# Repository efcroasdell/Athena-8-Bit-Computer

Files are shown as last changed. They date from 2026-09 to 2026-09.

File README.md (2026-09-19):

# Athena 8-Bit Computer

Athena is a practical 8-bit computer build and associated learning, measurement, verification, and documentation project.

This repository is the **authoritative engineering record** for Athena. Chat history may support the work, but established designs, measurements, decisions, experiments, faults, and evidence should be recorded here.

Athena is published as an engineering and learning record. Pull requests and issues are not currently accepted, but discussion and technical questions are welcome via GitHub Discussions.

## Scope

The repository is intended to hold:

- KiCad schematics and PCB/design files
- breadboard build records and wiring information
- photographs
- oscilloscope captures
- logic-analyser captures
- measurements and test results
- design decisions and architectural notes
- experiments and fault reports
- datasheets and reference material
- firmware, programs, scripts, and utilities
- superseded designs and failed experiments retained for historical and learning value

## Project boundary

**Athena is separate from Phoenix.**

Athena is the practical 8-bit computer build and its associated learning/documentation record. Phoenix is the separate modular computer architecture project centred on FPGA/Verilog and broader modular multi-processor exploration. Phoenix material must not be placed in this repository.

## Engineering approach

The project prioritises understanding, observability, and verification. Measurements, scope traces, logic-analyser captures, photographs, and controlled experiments are treated as engineering evidence rather than incidental artefacts.

Provisional ideas, confirmed decisions, superseded work, and failed experiments should remain distinguishable in the record rather than being silently overwritten.

Athena should favour understandable and verifiable solutions, but it need not always favour the most conventional solution. Unusual, historically interesting or unexpected period-appropriate devices and architectures may be explored where they add educational value, observability or understanding. Novelty is not itself a requirement and must not displace electrical correctness or clear verification.

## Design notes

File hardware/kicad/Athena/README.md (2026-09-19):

# Athena clock schematic

Open `Athena.kicad_pro` and enter the **Clock** sheet. `exports/Athena-clock.pdf` is the complete clock drawing on one A3 page.

The schematic now contains both halves of U1 (RS 305-838 / NE556), all five units of U2 (TI SN7400), U3 (TI SN74LS157N), U4 (TI CD40106BE), both timing networks, the RC/Schmitt STEP-debounce network, RUN/MANUAL controls, HLT gating, and only the two required LEDs. Signal paths are drawn with continuous wires. A dot at a crossing means connected; crossings without dots are not connected. Matching +5 V and ground symbols denote the common supply rails. PWR_FLAG is an electrical-check annotation, not a physical part.

## Defined connections

- U4 pin 1 is the debounce RC node: R3 = 47 kΩ to +5 V, C6 = 100 nF to GND, and R9 = 1 kΩ in series with SW1 to GND.
- U4 pin 2 feeds U4 pin 3; U4 pin 4 feeds U1 pin 8. This gives two Schmitt inversions and preserves the active-LOW STEP trigger polarity.
- U4 pin 14 is connected to +5 V and pin 7 to GND. Unused U4 inputs are tied to GND and unused outputs are marked unconnected.

- U1 pin 5 feeds U3 pin 3 (astable); U1 pin 9 feeds U3 pin 2 (manual).
- U2 pin 6 feeds U3 pin 1: LOW selects MANUAL, HIGH selects ASTABLE.
- U3 pin 4 feeds U2 pin 9. U2 pin 8 feeds U2 pins 12 and 13.
- U2 pin 11 is the external CPU_CLK output. No connector type or terminal numbering is assumed.
- U2 pin 10 is CLOCK_ENABLE. Closing SW3 pulls it LOW, lights D1 and holds CPU_CLK LOW.
- U3 pin 15 and unused data inputs are grounded; unused outputs are marked unconnected.
- U1A/B are one physical DIP-14 IC. U2A-E are one physical DIP-14 IC. U3 is DIP-16. U4A-G are one physical DIP-14 CD40106BE.

## Details still requiring confirmation

| Reference/detail | Meaning |
|---|---|
| R4, R5 | Fitted RUN/MANUAL pull-up resistances unknown: TBC |
| R7, R8 | Fitted HLT and astable LED series resistances unknown: TBC |
| D2 | Signal is confirmed as U1 pin 5; complete LED wiring/polarity to GND shown provisionally |
| RV1 unused end | Shown open; confirm whether strapped to the wiper |
| SW2 | Functional contacts shown; physical switch terminal numbering/type needs confirmation |
| C3, C4, C5 | Local supply bypass provisions for U1, U2, U3 respectively; fitted presence and values TBC |
| U4 local decoupling | Existing 100 nF rail decoupling is present close to the device on the breadboard; exact schematic reference/fitted placement remains to be reconciled if a dedicated capacitor reference is wanted |
| U3 unused data inputs | Grounded as required by the wiring record; verify actual breadboard connections |

U1 control pins 3 and 11 are externally unconnected in this drawing. Optional control bypass capacitors are not shown as fitted. The unknown details remain explicit rather than being guessed. Resolve them before using this as a definitive as-built record or final build specification. Footprints and PCB layout are outside this schematic update.

## Verification

The core connections follow `../../breadboard/clock/wiring.md`, `../../../docs/design-decisions/clock-architecture.md` and the user's confirmed values. All 44 IC pins were checked in the exported netlist, including power/reset, both timing networks, latch feedback, selector routing, HLT and LED connections. Actual pin membership was checked against expected sets to detect unintended joins.

KiCad **10.0.3** loaded the schematic in the existing Athena hierarchy. ERC reports **0 errors and 1 warning**: CPU_CLK is connected only to U2 pin 11 because the receiving CPU circuit is outside this module. This warning remains visible; no check was disabled to hide it. See `exports/Clock-erc.txt`.

The selector/output path was rechecked on the bench on 19 September 2026 and behaved correctly. The Clock schematic and Clock-logic sheet have now been revised to include the CD40106B STEP-debounce stage. The previously exported PDF/ERC files pre-date this revision and must be regenerated in KiCad 10.0.3 before they are treated as current verification artefacts.

The original top-level schematic and existing project settings were retained. Journal content was not edited as part of this work.

## Logic diagram

The **Clock logic** hierarchical sheet (`Clock-logic.kicad_sch`) now also identifies the CD40106B STEP-conditioning stage before the manual 556 path, alongside source selection, mode memory, both HLT NAND gates and the Boolean relationships. `exports/Clock-logic.pdf` is its A4 preview. This sheet contains documentation graphics only and is excluded from the BOM, board and simulation. Its U1/U2/U3 annotations refer to the existing physical ICs on the Clock circuit sheet; it adds no duplicate parts or electrical nets.

## 19 September 2026 schematic update

The Clock sheet has been revised to match the current physical STEP path:

- CD40106B pin 1 → 47 kΩ → +5 V;
- CD40106B pin 1 → 100 nF → GND;
- CD40106B pin 1 → 1 kΩ → STEP switch → GND;
- CD40106B pin 2 → pin 3;
- CD40106B pin 4 → U1 pin 8;
- CD40106B pin 14 → +5 V;
- CD40106B pin 7 → GND;
- unused CD40106B inputs are tied to GND; unused outputs are marked unconnected.

The former direct 10 kΩ pull-up / STEP-switch connection at U1 pin 8 is superseded. R3 is now 47 kΩ, C6 is 100 nF and R9 is 1 kΩ.

Bench verification on 19 September 2026 established that the conditioning stage produces a clean trigger at U1 pin 8 and one clean CPU clock pulse per deliberate STEP action. In RUN, STEP produced no observable disturbance at U3 pin 4, U2 pin 9 or U2 pin 11.

**Export status:** the editable KiCad schematic files are current, but the committed PDF preview and ERC report still represent the earlier revision until regenerated in KiCad 10.0.3.

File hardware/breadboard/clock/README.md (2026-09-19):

# Athena Clock Module

## Purpose

The Athena clock module provides the timing and manual stepping functions required by the 8-bit computer while preserving the user-facing behaviour of the original Ben Eater clock module:

- variable-speed free-running clock
- manual single-step clock
- RUN/MANUAL mode selection
- HLT-controlled clock gating
- final CPU clock output
- observable intermediate signals for verification and learning

The current implementation is intentionally compact but remains built from discrete TTL-era functions so that each stage can be observed and understood directly.

## Current architecture

The current clock uses four main ICs:

| Device | Function in Athena |
|---|---|
| RS 305-838 dual 556 timer | Timer 1: astable free-running clock. Timer 2: monostable manual STEP pulse. |
| TI CD40106BE hex Schmitt-trigger inverter | RC + hysteretic conditioning of the mechanical STEP input. Two inverter stages preserve active-LOW trigger polarity. |
| TI SN7400 standard TTL quad NAND | RUN/MANUAL latch and HLT clock gating. |
| TI SN74LS157N quad 2-to-1 multiplexer | Selects manual or astable clock source. |

Functional signal path:

1. 556 Timer 1 generates the variable-speed astable clock.
2. The STEP push-button is filtered by a 47 kΩ / 100 nF RC network and two CD40106B Schmitt inverters.
3. 556 Timer 2 generates one monostable pulse for each clean active-LOW STEP trigger.
4. The SN7400 cross-coupled NAND latch stores the RUN/MANUAL state.
5. The SN74LS157 selects either the manual pulse or the astable clock according to the stored mode.
6. The remaining SN7400 gates apply HLT control to the selected clock.
7. SN7400 pin 11 is the final internal CPU clock output.

## 556 pinout used in this build

The RS 305-838 dual 556 pinout has been verified as:

| Pin | Signal |
|---:|---|
| 1 | DISCHARGE1 |
| 2 | THRESHOLD1 |
| 3 | CONTROL1 |
| 4 | RESET1 |
| 5 | OUTPUT1 |
| 6 | TRIGGER1 |
| 7 | GND |
| 8 | TRIGGER2 |
| 9 | OUTPUT2 |
| 10 | RESET2 |
| 11 | CONTROL2 |
| 12 | THRESHOLD2 |
| 13 | DISCHARGE2 |
| 14 | VCC |

Timer 1 is configured as an astable oscillator. Timer 2 is configured as a monostable single-step generator.

## Timer 1: astable clock

Current functional connections:

- pin 14 → +5 V
- pin 7 → GND
- pin 4 → +5 V
- pins 2 and 6 joined as the timing-capacitor node
- fixed timing resistor from +5 V to pin 1
- 1 MΩ speed-control potentiometer between pin 1 and the joined pins 2/6
- 1 µF timing capacitor from pins 2/6 to GND
- pin 5 = astable clock output

The timing node repeatedly charges and discharges between approximately one-third and two-thirds of VCC. The internal threshold and trigger comparators change the state of the timer latch at those points, while the discharge transistor on pin 1 controls the capacitor discharge interval.

## Timer 2: manual STEP monostable

Current functional connections:

- pin 8 = active-LOW STEP trigger driven by CD40106B pin 4
- CD40106B pin 1 is the debounce node: 47 kΩ to +5 V, 100 nF to GND, and 1 kΩ in series with the normally-open STEP switch to GND
- CD40106B pin 2 → pin 3; pin 4 → 556 pin 8
- pin 9 = monostable output
- pin 10 → +5 V
- pin 11 normally unconnected; optional small control-voltage bypass may be fitted
- pins 12 and 13 joined as the monostable timing node
- 1 MΩ timing resistor from +5 V to pins 12/13
- 1 µF timing capacitor from pins 12/13 to GND

At rest, the CD40106B holds pin 8 HIGH and pin 9 is LOW. Pressing STEP discharges the RC node; the Schmitt thresholds convert the slow, potentially bouncing mechanical transition into one clean LOW-going trigger at pin 8. Pulling pin 8 below the internal trigger threshold sets the internal latch, drives pin 9 HIGH, turns the discharge transistor off, and allows the timing capacitor to charge. When the timing node reaches the upper threshold, the threshold comparator resets the latch, pin 9 returns LOW, and the discharge transistor restores the timing node to its idle state.

## SN7400 functions

The SN7400 uses all four NAND gates.

| Gate | Pins | Function |
|---|---|---|
| Gate 1 | 1,2 → 3 | First half of cross-coupled RUN/MANUAL latch |
| Gate 2 | 4,5 → 6 | Second half of cross-coupled RUN/MANUAL latch; pin 6 is Q |
| Gate 3 | 9,10 → 8 | First stage of HLT clock gating |
| Gate 4 | 12,13 → 11 | Inverts gate-3 result to restore final clock polarity |

Pin 6, Q, drives the SELECT input of the SN74LS157.

HLT control is applied at SN7400 pin 10. The current behaviour has been verified:

- pin 10 HIGH → selected clock passes through to pin 11 with the intended polarity
- pin 10 LOW → final clock pin 11 is held LOW

An HLT indicator LED is connected so that it illuminates when the HLT control node is LOW.

## SN74LS157 clock-source selector

Channel 1 is used for clock selection:

| Pin | Function in Athena |
|---:|---|
| 1 | SELECT ← SN7400 pin 6 (Q) |
| 2 | 1A ← 556 pin 9 manual STEP output |
| 3 | 1B ← 556 pin 5 astable output |
| 4 | 1Y → SN7400 pin 9 selected-clock input |
| 8 | GND |
| 15 | active-LOW strobe tied to GND |
| 16 | +5 V |

The selector function is:

Y = A·Q̄ + B·Q

so one clock source is selected according to the stored RUN/MANUAL state.

Unused LS157 data inputs are intended to be tied to a defined logic level rather than left floating. Unused outputs may remain open.

## Current verification status

Confirmed so far:

- 556 Timer 1 astable operation and timing-node behaviour
- 556 Timer 2 pin 8 active-LOW trigger behaviour
- 556 Timer 2 pin 9 idle LOW state and triggered HIGH pulse
- 556 Timer 2 pin 10 steady HIGH reset input
- 556 Timer 2 pin 11 steady control/reference level
- 556 Timer 2 pin 12 idle timing-node level and triggered exponential charge followed by rapid discharge
- CD40106B STEP debounce operation
- one STEP press producing one clean CPU clock pulse in the post-debounce DSLogic capture
- SN7400 RUN/MANUAL latch operation
- SN7400 HLT gating behaviour
- SN74LS157 enable state and SELECT input operation
- RUN-mode rejection of the manual STEP path verified at SN74LS157 pin 4, SN7400 pin 9 and SN7400 pin 11
- final CPU clock independently measured at approximately 270.407 kHz during the 19 September 2026 RUN-mode regression check

Systematic pin-by-pin 556 verification has reached pin 12, with pins 8, 9 and 12 checked in both idle and triggered states. Pins 13 and 14 remain to be documented. The manual STEP debounce and selector propagation path are now independently verified.

## Evidence and measurement record

Detailed oscilloscope measurements, expected behaviour, observed values, and explanations of the internal 556 mechanisms belong in the corresponding measurement journal under `docs/measurements/`.

Photographs and oscilloscope captures should be stored under `evidence/` and referenced from the journal by filename so that the written conclusion remains tied to the original evidence.

## Status

**Current architectural decision:** 556 + SN7400 + SN74LS157 implementation.

**Current verification state:** the clock architecture, RUN/MANUAL selection, HLT gating and debounced manual STEP path are functionally verified; remaining work is completion of the formal pin-by-pin 556 documentation and evidence indexing.

**Project boundary:** this clock module belongs to Athena. Phoenix FPGA/multi-processor architecture material is not part of this repository.

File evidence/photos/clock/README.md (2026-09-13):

# Clock Module Photographic Evidence

Store photographs of the Athena clock-module breadboard and component wiring in this directory.

Photographs are engineering evidence. Each image should be treated as a record of the circuit at that moment rather than as an illustration of what the circuit was expected to be.

Use filenames that identify the subject and date where practical, for example:

- `clock-overview-2026-09-13.jpg`
- `556-step-switch-wiring-2026-09-13.jpg`
- `556-timer2-timing-network-2026-09-13.jpg`
- `sn7400-run-manual-latch-2026-09-13.jpg`
- `sn74ls157-clock-selector-2026-09-13.jpg`

Where a photograph is used to support a wiring or fault conclusion, reference its filename from the corresponding Markdown record.

Project rule: **every photograph is fresh evidence**. Trace only connections that are actually visible. Do not infer a missing connection from the expected schematic or from an earlier photograph.

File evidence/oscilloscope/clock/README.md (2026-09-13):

# Clock Module Oscilloscope Evidence

Store original oscilloscope captures for the Athena clock module in this directory.

Use filenames that identify the device, pin or node, state and date where practical. Examples:

- `556-pin01-discharge1-2026-09-13.jpg`
- `556-pin08-trigger2-idle-2026-09-13.jpg`
- `556-pin08-trigger2-pressed-2026-09-13.jpg`
- `556-pin09-output2-idle-2026-09-13.jpg`
- `556-pin09-output2-triggered-2026-09-13.jpg`

The written measurement record belongs in `docs/measurements/clock-556-verification.md` and should link to the original evidence files stored here.

Do not alter an original capture merely to make it agree with an expected result. If annotated or cropped versions are useful, retain the original and store the derivative with a clearly different filename.

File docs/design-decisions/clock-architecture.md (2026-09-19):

# Clock Architecture Decision Record

Status: **current architectural decision**

## Decision

Athena's clock module will retain the functional behaviour of the Ben Eater 8-bit computer clock while using a more compact implementation based on:

- one RS 305-838 dual 556 timer
- one TI CD40106BE hex Schmitt-trigger inverter
- one TI SN7400 standard TTL quad NAND gate
- one TI SN74LS157N quad 2-to-1 multiplexer

This is an Athena decision. It is not a Phoenix architectural rule.

## Required external behaviour

The clock module must provide:

- variable-speed free-running clock
- manual single-step operation with hardware debounce and hysteretic edge conditioning
- persistent RUN/MANUAL mode selection
- clean clock-source selection
- HLT-controlled clock gating
- final CPU clock output
- observable intermediate nodes for measurement and diagnosis

## Functional allocation

### 556 Timer 1 — astable source

Timer 1 produces the free-running variable-speed clock. The timing capacitor repeatedly traverses the internal trigger and threshold reference levels, approximately one-third and two-thirds of VCC. The internal latch and discharge transistor create the repeating charge/discharge cycle.

### CD40106B — STEP input conditioning

The mechanical STEP input is conditioned before it reaches the 556.

The current network is:

- 47 kΩ from the CD40106B pin-1 debounce node to +5 V;
- 100 nF from the pin-1 node to GND;
- 1 kΩ from the pin-1 node through the normally-open STEP switch to GND;
- CD40106B pin 2 connected to pin 3;
- CD40106B pin 4 driving 556 pin 8.

Two Schmitt inverter stages are used so that hysteresis cleans the mechanical transition while the second inversion restores the required active-LOW trigger polarity.

### 556 Timer 2 — manual monostable

Timer 2 produces one manual clock pulse for each clean active-LOW STEP trigger from the CD40106B. Its timing interval is determined by the external 1 MΩ / 1 µF timing network.

### SN7400 gates 1 and 2 — RUN/MANUAL memory

The first two NAND gates are cross-coupled to form an SR latch. The latch stores the selected operating mode rather than requiring the selector switch itself to carry the clock signal.

The chosen convention is:

- SN7400 pin 6 = Q
- SN7400 pin 3 = complementary output

Q drives the SELECT input of the SN74LS157.

### SN74LS157 — clock-source selection

One multiplexer channel selects between:

- A = manual pulse from 556 pin 9
- B = astable clock from 556 pin 5

with Q from the SN7400 latch controlling SELECT.

The intended selector relationship is:

`Y = A·Q̄ + B·Q`

The active-LOW strobe is tied LOW so the selector remains enabled.

### SN7400 gates 3 and 4 — HLT gating

The remaining two NAND gates provide the final HLT gating function. The two-gate arrangement restores the selected clock to the intended polarity at the final output.

Verified behaviour:

- HLT control HIGH → selected clock propagates to final clock output
- HLT control LOW → final clock output is held LOW

SN7400 pin 11 is the current final internal CPU clock output.

## Why this architecture was chosen

The design keeps the full educational value of the original clock while reducing package count and making the signal path explicit.

The implementation exposes several distinct concepts in one small subsystem:

- analogue RC timing
- internal comparator thresholds
- SR-latch state
- TTL NAND logic
- multiplexing
- active-LOW control
- clock gating
- propagation through multiple logic stages
- oscilloscope verification of analogue and digital behaviour

The 556 is particularly useful because it places the astable and monostable functions in one package while preserving the same internal timer mechanisms that can be observed and understood individually.

The CD40106B was not selected by following an existing Z80 clock plan. It was introduced after measurement and fault isolation showed that repeated clock events originated in mechanical STEP-input chatter. The design therefore arose from the observed failure mechanism: contact bounce required a slowly varying RC node to be converted into a single unambiguous logic transition, for which a Schmitt input is directly suited.

This is an important Athena design principle: the project should prefer understandable and verifiable solutions, but it need not always choose the most conventional solution. Unusual, historically interesting or unexpected period-appropriate devices and architectures may be explored where they increase educational value, observability or understanding. Novelty is not itself a requirement and must not obscure electrical correctness.

## Rejected or superseded approaches

### Multiple 555 timers

The original learning path used separate 555 timers. This remains historically important and is retained in the archive, but it is not the current Athena clock architecture.

Reason for supersession: the dual 556 implements the two required timer functions in one package without hiding the timing mechanism.

### Treating the RUN/MANUAL control as direct clock switching

Rejected. Mode state is retained in the NAND latch and then applied to the multiplexer. This makes the state explicit and independently observable.

### Alternative STEP-debounce approaches considered

The following alternatives were investigated before the CD40106B implementation was selected:

- CD4093BE Schmitt NAND logic;
- comparator-based hysteresis using LM393, HA17393 or AN1319 devices;
- a NAND SR-latch debounce circuit with an SPDT momentary switch;
- 74LS123 monostable conditioning;
- flip-flop-based approaches;
- altering the existing 556 trigger network.

These alternatives remain technically interesting. They were not rejected as invalid in general; they were not selected for this milestone because the CD40106B directly addresses the observed bounce mechanism with fewer additional parts and a clear test method.

### Moving the clock function into FPGA logic

Not part of the current Athena clock milestone. The purpose of this module is to understand and measure the physical timer, TTL, switching and gating behaviour directly.

## Observability requirement

The following points should remain practically observable during development:

- 556 astable timing node
- 556 astable output
- mechanical STEP switch
- CD40106B RC debounce node
- CD40106B conditioned STEP output
- 556 monostable trigger
- 556 monostable output
- RUN/MANUAL latch outputs
- LS157 SELECT
- LS157 selected clock output
- HLT control
- final CPU clock

Observability is a design objective, not an incidental debugging convenience.

## Verification requirement

The architecture is not considered fully verified merely because the final clock appears to work. Each stage must be checked against its expected behaviour and, where useful, against the internal mechanism that produces that behaviour.

The manual STEP debounce and complete selector/final-clock propagation path were rechecked end-to-end on 19 September 2026. One STEP press produced one clean CPU clock pulse in the post-debounce logic-analyser capture, and in RUN mode a STEP action produced no observable disturbance at SN74LS157 pin 4, SN7400 pin 9 or SN7400 pin 11. Formal pin-by-pin documentation of the remaining 556 pins continues separately.

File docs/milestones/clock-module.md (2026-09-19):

# Athena Milestone — Clock Module

Status: **in progress**

## Purpose

Produce and verify a complete clock subsystem for Athena that preserves the functional behaviour required by the Ben Eater 8-bit computer while making each timing, selection and gating stage observable and understandable.

## Current implementation

- RS 305-838 dual 556
  - Timer 1: variable-speed astable clock
  - Timer 2: manual monostable STEP pulse
- TI CD40106BE
  - RC + Schmitt-trigger conditioning of the mechanical STEP input
- TI SN7400
  - RUN/MANUAL state latch
  - HLT clock gating
- TI SN74LS157N
  - manual/astable clock-source selection

## Prerequisites

- stable +5 V supply
- common ground reference
- verified IC orientation and pinout
- oscilloscope available for analogue timing and digital waveform checks
- known-good STEP, RUN/MANUAL and HLT controls

## Model

The clock module consists of five observable functional stages:

1. generation of a free-running clock by the 556 astable timer;
2. RC filtering and Schmitt-trigger conditioning of the mechanical STEP input;
3. generation of one manual pulse by the 556 monostable timer;
4. persistent RUN/MANUAL state stored by the SN7400 latch and applied to the SN74LS157 selector;
5. HLT gating of the selected clock through the remaining SN7400 gates.

The final internal CPU clock is SN7400 pin 11.

## Expected behaviour

### Astable mode

The timing capacitor repeatedly charges and discharges between approximately one-third and two-thirds of VCC. 556 pin 5 produces a corresponding square-wave clock whose frequency varies with the speed potentiometer.

### Manual mode

The STEP switch acts on a 47 kΩ / 100 nF RC node at CD40106B pin 1. Schmitt hysteresis converts the mechanical transition into a clean logic event. A second inverter restores the original polarity so 556 pin 8 is HIGH at rest and receives one clean LOW-going trigger for each valid STEP action. Pin 9 then produces one HIGH monostable pulse before returning automatically to LOW.

### Selection

The SN7400 RUN/MANUAL latch retains the chosen mode. Its Q output drives SN74LS157 SELECT so that only the appropriate clock source reaches the selected-clock output.

### Halt

HLT inactive permits the selected clock to propagate to the final clock output. HLT active forces the final clock LOW.

## Observability

The following nodes must remain measurable during this milestone:

- Timer 1 discharge node
- Timer 1 timing capacitor / threshold / trigger node
- Timer 1 control reference
- Timer 1 output
- mechanical STEP switch
- CD40106B debounce RC node
- CD40106B conditioned output
- Timer 2 trigger
- Timer 2 output
- Timer 2 timing node
- RUN/MANUAL latch Q and complementary output
- LS157 SELECT
- LS157 selected-clock output
- HLT control
- final CPU clock

## Predicted results

- Timer 1 timing node: ramp between roughly one-third and two-thirds VCC
- Timer 1 output: clean TTL-compatible square wave
- Timer 2 trigger: HIGH at rest, LOW while STEP is pressed
- Timer 2 output: LOW at rest, one HIGH pulse per valid trigger
- RUN/MANUAL latch: stable complementary states until deliberately changed
- selected clock: only the chosen source appears at LS157 output
- HLT active: final clock remains LOW
- HLT inactive: final clock follows selected source with intended polarity

## Acceptance criteria

The clock milestone is complete when:

- all relevant 556 pins have been measured and documented;
- astable frequency changes predictably with the speed control;
- one STEP action produces one clean manual output pulse and one clean final CPU clock event;
- RUN/MANUAL state is stable and repeatable;
- source selection is verified at the LS157 input and output pins;
- HLT reliably suppresses the final clock;
- final clock waveform is measured directly;
- no input required to hold a defined state is left floating;
- the current breadboard wiring record matches the physical build;
- evidence files are linked from the measurement record.

## Fault tests

Controlled tests should include:

- force Timer 2 trigger LOW with a jumper and confirm the expected response;
- change RUN/MANUAL state and confirm LS157 SELECT changes accordingly;
- activate HLT while the astable source continues running and confirm only the final clock is suppressed;
- verify that removing a control action returns the node to its defined pull-up or stable state;
- where a waveform is suspicious, distinguish source behaviour from probe/ground artefacts before assigning a component fault.

## Required documentation

- `hardware/breadboard/clock/README.md`
- `hardware/breadboard/clock/wiring.md`
- `docs/design-decisions/clock-architecture.md`
- `docs/measurements/clock-556-verification.md`
- `docs/faults/clock-fault-history.md`
- oscilloscope evidence under `evidence/oscilloscope/clock/`
- breadboard photographs under `evidence/photos/clock/`

## Current state

**Completed sub-milestone, 19 September 2026:** manual STEP input debouncing and clean single-clock generation verified.

Evidence and checks completed:

- switch chatter traced to the 556 trigger input;
- a better tactile switch reduced but did not eliminate bounce;
- a CD40106BE RC + Schmitt-trigger conditioner was derived from the measured failure mechanism and installed;
- the conditioned trigger was verified by oscilloscope;
- a retained DSLogic capture showed one clean CPU clock pulse per deliberate STEP action;
- RUN/MANUAL selector propagation was rechecked at SN74LS157 pin 1, SN74LS157 pin 4, SN7400 pin 9 and SN7400 pin 11;
- RUN-mode final CPU clock was independently measured at approximately 270.407 kHz during the regression check.

The overall clock milestone remains **in progress** because the formal pin-by-pin 556 record still has pins 13 and 14 to document and the evidence index requires completion.

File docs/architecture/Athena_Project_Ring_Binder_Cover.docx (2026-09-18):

ATHENA

8-BIT COMPUTER PROJECT

Engineering Record & Learning Journal

━━━━━━━━━━━━━━━━━━━━━━━━━━━━━━━━━━━━

DESIGN • BUILD • VERIFY • OBSERVE • UNDERSTAND

A practical, evidence-led computer engineering project exploring the design and construction of an observable 8-bit computer system from first principles.

Clock • CPU • Single-T-State Stepping • Buses • Memory • I/O • Firmware • Measurements • Faults • Design Decisions • Schematics • Test Evidence

Project owner | Edward Croasdell
Started | 2026
Repository | efcroasdell/Athena-8-Bit-Computer
Record | Printed master binder supported by the online engineering repository

UNDERSTANDING BEFORE COMPLETION

The project is successful when each subsystem can be explained, predicted, measured, diagnosed and deliberately modified.

ATHENA

DOCUMENT CHANGELOG

Printed Ring-Binder Record

This page records substantive changes to the printed Athena project documentation. The GitHub repository remains the authoritative online engineering record; the binder is a maintained physical project record.

Date | Revision | Documents | Change
18 Sep 2026 | 1.1 | Front matter; Clock Module record; Z80 CPU Bring-up record | Initial binder cover and technical records established. Documentation updated to state explicitly that MANUAL/STEP produces one CPU_CLK pulse per press and therefore permits a connected Z80 to advance one T-state at a time for timing-diagram, bus and control-signal observation.

Current printed set

- Front cover and changelog
- Athena Clock Module — Build, Verification and Learning Record
- Athena Z80 CPU Bring-up — Progress, Evidence and Learning Record

Change-control principle

Corrections, new measurements and later as-built changes should be dated and recorded without erasing the historical sequence that led to them.

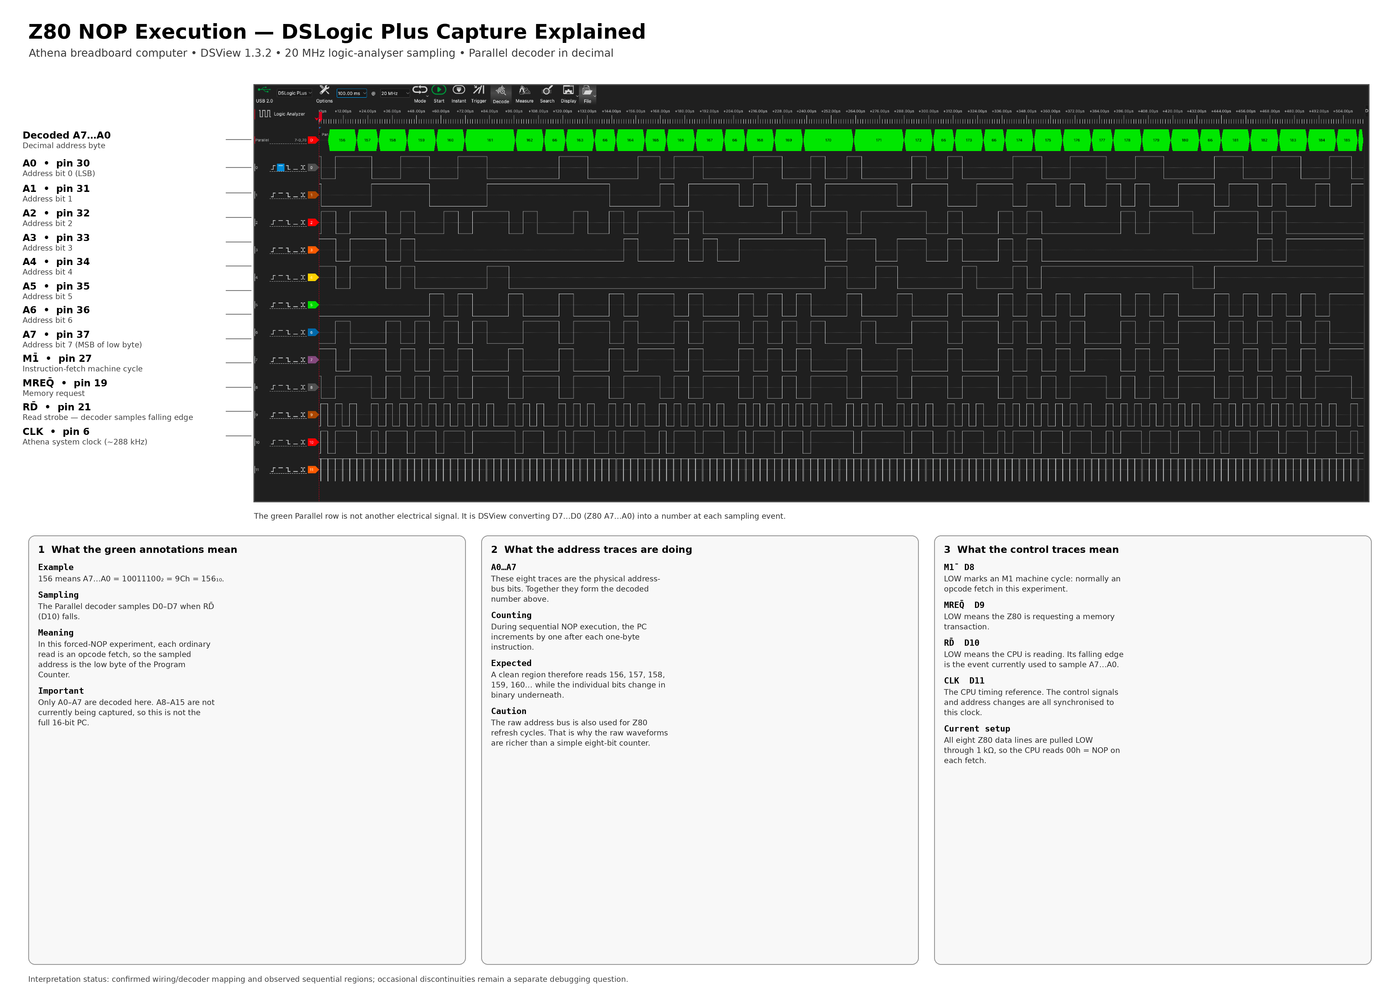
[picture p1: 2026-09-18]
Z80 CPU/Logic Analyser/Z80_DSLogic_Annotated_Capture_A3.png

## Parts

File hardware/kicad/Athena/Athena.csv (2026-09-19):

Reference | Qty | Value | DNP | Exclude from BOM | Exclude from Board | Footprint | Datasheet | Description
C1,C2 | 2 | 1uF
C6 | 1 | 100n
C3,C4,C5,R4,R5,R7,R8 | 7 | TBC
D1,SW3 | 2 | HLT
D2 | 1 | ASTABLE
R1 | 1 | 1k
R2,RV1 | 2 | 1M
R3 | 1 | 47k
R6 | 1 | 10k
R9 | 1 | 1k
SW1 | 1 | STEP (N.O.)
SW2 | 1 | RUN / MANUAL
U1 | 1 | NE556
U2 | 1 | SN7400
U3 | 1 | 74LS157
U4 | 1 | CD40106BE |  |  |  |  | https://www.ti.com/lit/ds/symlink/cd40106b.pdf | Hex Schmitt-trigger inverter

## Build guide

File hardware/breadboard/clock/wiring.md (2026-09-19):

# Athena Clock Module — Wiring Record

Status: **current working breadboard wiring**

This file records the wiring of the present Athena clock module. It is intended to describe the circuit as actually built and verified, not an idealised future design.

## Supply convention

- Logic supply: +5 V
- Ground: common 0 V reference
- All IC supply pins require local decoupling appropriate to the final build.

## RS 305-838 dual 556

Verified pinout:

| Pin | Signal | Current connection |
|---:|---|---|
| 1 | DISCHARGE1 | Astable timing network; fixed resistor from +5 V and 1 MΩ speed potentiometer to pins 2/6 node |
| 2 | THRESHOLD1 | Joined to pin 6 and 1 µF timing capacitor to GND |
| 3 | CONTROL1 | Internal control-voltage reference; no functional external control connection required for current build |
| 4 | RESET1 | +5 V |
| 5 | OUTPUT1 | Astable clock output; feeds SN74LS157 channel-1 B input |
| 6 | TRIGGER1 | Joined to pin 2 and 1 µF timing capacitor to GND |
| 7 | GND | GND |
| 8 | TRIGGER2 | Driven by CD40106B pin 4; HIGH at rest and driven LOW by the debounced STEP path |
| 9 | OUTPUT2 | Manual monostable output; feeds SN74LS157 channel-1 A input |
| 10 | RESET2 | +5 V |
| 11 | CONTROL2 | Normally unconnected in current build |
| 12 | THRESHOLD2 | Joined to pin 13; 1 MΩ to +5 V and 1 µF to GND |
| 13 | DISCHARGE2 | Joined to pin 12 timing node |
| 14 | VCC | +5 V |

### Timer 1 astable timing network

- +5 V → fixed timing resistor → pin 1
- pin 1 → 1 MΩ speed potentiometer → pins 2/6
- pins 2/6 → 1 µF → GND
- pin 5 = free-running clock output

The 1 MΩ potentiometer is used as the variable timing resistance between pin 1 and the joined pins 2/6. The wiper is the active connection to the timing node; the unused outer terminal may be tied to the wiper as a fail-safe against an open wiper.

### Timer 2 monostable timing and STEP network

The STEP trigger is now conditioned by a CD40106B Schmitt-trigger stage before reaching pin 8.

- CD40106B pin 4 → 556 pin 8
- pins 12/13 → 1 MΩ → +5 V
- pins 12/13 → 1 µF → GND
- pin 9 = manual STEP pulse output

The former direct 10 kΩ pull-up and push-button connection at 556 pin 8 has been removed. Pin 8 is now actively driven by CD40106B pin 4.

## TI CD40106BE hex Schmitt-trigger inverter

Two inverter stages are used so that the debounced signal presented to the 556 retains the original active-LOW STEP polarity.

| Pin | Current connection |
|---:|---|
| 1 | Debounce RC node |
| 2 | First Schmitt inverter output; connected to pin 3 |
| 3 | Second Schmitt inverter input; connected from pin 2 |
| 4 | Debounced STEP output → 556 pin 8 |
| 5 | Unused input tied to GND |
| 6 | Unused output; unconnected |
| 7 | VSS → GND |
| 8 | Unused output; unconnected |
| 9 | Unused input tied to GND |
| 10 | Unused output; unconnected |
| 11 | Unused input tied to GND |
| 12 | Unused output; unconnected |
| 13 | Unused input tied to GND |
| 14 | VDD → +5 V |

### STEP debounce network

- CD40106B pin 1 → 47 kΩ → +5 V
- CD40106B pin 1 → 100 nF → GND
- CD40106B pin 1 → 1 kΩ → normally-open STEP switch → GND
- CD40106B pin 2 → pin 3
- CD40106B pin 4 → 556 pin 8

Existing 100 nF rail decoupling is present close to the logic devices. The 100 nF capacitor on pin 1 is not a supply-decoupling capacitor; it is part of the RC debounce network.

At rest, the 47 kΩ resistor charges the pin-1 node HIGH. Pressing STEP discharges the node through 1 kΩ. Schmitt hysteresis prevents contact bounce and the slow RC transition from producing multiple logic transitions. The two inversions restore the required HIGH-at-rest, LOW-on-STEP polarity at 556 pin 8.

## TI SN7400 standard TTL quad NAND

| Pin | Function in current clock module |
|---:|---|
| 1 | Gate 1 input A; switch-driven latch input, normally pulled HIGH and switched LOW |
| 2 | Gate 1 input B; feedback from pin 6 |
| 3 | Gate 1 output; complementary latch output, feeds pin 5 |
| 4 | Gate 2 input A; switch-driven latch input, normally pulled HIGH and switched LOW |
| 5 | Gate 2 input B; feedback from pin 3 |
| 6 | Gate 2 output Q; drives SN74LS157 pin 1 SELECT |
| 7 | GND |
| 8 | Gate 3 output; feeds pins 12 and 13 |
| 9 | Gate 3 clock input; receives selected clock from SN74LS157 pin 4 |
| 10 | HLT/CLOCK_ENABLE input; 10 kΩ pull-up to +5 V, HLT switch pulls LOW |
| 11 | Gate 4 output; final internal CPU clock |
| 12 | Gate 4 input A; tied to pin 8 |
| 13 | Gate 4 input B; tied to pin 8 |
| 14 | +5 V |

### HLT indicator

Current indicator connection:

- +5 V → current-limiting resistor → LED anode
- LED cathode → SN7400 pin 10 HLT node

The LED therefore illuminates when HLT is active and the pin-10 node is LOW.

## TI SN74LS157N selector

Channel 1 performs RUN/MANUAL clock selection.

| Pin | Current connection |
|---:|---|
| 1 | SELECT ← SN7400 pin 6 Q |
| 2 | 1A ← 556 pin 9 manual STEP output |
| 3 | 1B ← 556 pin 5 astable output |
| 4 | 1Y → SN7400 pin 9 selected-clock input |
| 8 | GND |
| 15 | active-LOW strobe tied to GND |
| 16 | +5 V |

Unused LS157 data inputs are to be tied to a defined logic level, normally GND. Unused outputs may remain unconnected.

## Current signal chain

`STEP switch` → `CD40106B RC + Schmitt conditioning` → `556 pin 8 trigger` → `556 pin 9 manual pulse`, while `556 pin 5` supplies the astable clock; the two sources then feed `SN74LS157 selector` → `SN7400 HLT gating` → `SN7400 pin 11 final CPU clock`

The RUN/MANUAL latch output on SN7400 pin 6 controls which 556 output the SN74LS157 selects.

## Verification state

Verified on the current breadboard:

- Timer 1 astable activity
- CD40106B debounce RC node transitions cleanly between HIGH and LOW
- CD40106B output provides a clean active-LOW trigger at 556 pin 8
- Timer 2 trigger HIGH at rest and LOW on STEP press
- Timer 2 output LOW at rest and HIGH for the monostable pulse
- one manual STEP action produces one clean CPU clock pulse in the post-debounce DSLogic capture
- RUN/MANUAL latch state change
- HLT gating behaviour
- LS157 strobe LOW and SELECT input changing with latch Q
- in RUN mode, STEP produces no observable disturbance at LS157 pin 4, SN7400 pin 9 or SN7400 pin 11

The selector and final clock propagation path were rechecked end-to-end on 19 September 2026 and behaved as designed.

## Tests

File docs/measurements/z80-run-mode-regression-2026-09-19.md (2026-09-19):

# Athena Measurement Record — Z80 RUN-Mode Regression Check

Date: **19 September 2026**

Status: **verified for the captured configuration**

## Purpose

Confirm that the Z80 system remained operational after substantial rebuilding, STEP-switch diagnosis, addition of the CD40106B debounce stage, and repeated movement of temporary test leads.

## Test configuration

- Z80 in the established forced-NOP bring-up configuration
- A0–A7 observed on DSLogic Plus D0–D7
- M1̄ on D8
- MREQ̄ on D9
- RD̄ on D10
- CPU CLK on D11
- RUN mode selected
- final CPU clock measured at Z80 pin 6

## Clock-frequency cross-check

The Long Wei TFC-2700L frequency counter was connected to the final CPU clock node at Z80 pin 6, with the counter reference connected to Athena circuit ground.

Observed frequency:

**approximately 270.407 kHz**

This agreed with the recent oscilloscope and logic-analyser observations of the Athena clock in the approximately 270–280 kHz region.

## Logic-analyser observations

At the normal RUN-mode clock rate:

- A0–A7 behaved as independent address lines rather than moving together;
- A0 changed most rapidly, with each successively higher address bit changing less frequently;
- the resulting pattern showed the expected binary hierarchy;
- M1̄, MREQ̄ and RD̄ were active and regular;
- the capture was consistent with continued forced-NOP execution.

## Interpretation

### Observed fact

The clock, address bus and captured control lines all showed coherent activity after the clock-module rebuilding and STEP-debounce work.

### Deduction

The current RUN-mode baseline is therefore restored: the rebuilding did not introduce a persistent fault into the normal forced-NOP execution path.

## Transient selector anomaly

During debugging, a manual STEP action appeared briefly to influence the clock while RUN was selected. Because many temporary leads had been moved during the investigation, the propagation path was checked directly rather than assuming a selector fault.

Measured:

- SN74LS157 pin 1: 0 V in MANUAL and approximately 3.6 V in RUN;
- SN74LS157 pin 4: no STEP-correlated change in RUN;
- SN7400 pin 9: no STEP-correlated change in RUN;
- SN7400 pin 11: no STEP-correlated change in RUN.

The anomaly could not be reproduced after the wiring was stabilised. It is retained in the record as a debugging/probing artefact rather than promoted into a circuit fault.

## Evidence

The corresponding healthy RUN-mode DSView capture from 19 September 2026 was also recreated as a print-friendly annotated figure using the same white-background annotation style as the earlier CPU bring-up figure.

The figure explains:

- the Parallel decoder output;
- A0–A7 address-line behaviour;
- M1̄, MREQ̄ and RD̄;
- the CPU CLK reference;
- why the observed pattern is consistent with forced-NOP address progression.

Raw analyser captures and the annotated print figure should be preserved under `evidence/logic-analyser/` when binary evidence files are committed.

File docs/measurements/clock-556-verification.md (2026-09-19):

# Athena Clock Module — 556 Pin Verification Journal

Status: **in progress**

This journal records systematic pin-by-pin verification of the RS 305-838 dual 556 used in the Athena clock module.

The aim is not merely to confirm logic levels. Each measurement is related to the relevant internal timer mechanism so that the observed waveform can be used as evidence for the working model of the IC.

## Device pinout

| Pin | Signal |
|---:|---|
| 1 | DISCHARGE1 |
| 2 | THRESHOLD1 |
| 3 | CONTROL1 |
| 4 | RESET1 |
| 5 | OUTPUT1 |
| 6 | TRIGGER1 |
| 7 | GND |
| 8 | TRIGGER2 |
| 9 | OUTPUT2 |
| 10 | RESET2 |
| 11 | CONTROL2 |
| 12 | THRESHOLD2 |
| 13 | DISCHARGE2 |
| 14 | VCC |

---

### Pin 1 — DISCHARGE1

**What it does:** Pin 1 is connected to the collector of Timer 1's internal discharge transistor. The transistor is controlled by the state of the timer's internal SR latch. When the discharge transistor is ON, it provides a low-resistance path towards ground for the timing network; when it is OFF, the timing capacitor is allowed to charge through the external resistors.

**What is connected to it:** The astable timing network. A fixed resistor connects from +5 V to pin 1, and the variable timing resistance connects from pin 1 to the joined pins 2/6 timing node.

**Expected:** A switching waveform between near ground and a high level at the astable repetition rate.

**Why:** During the charging interval, the discharge transistor is OFF and pin 1 rises through the external resistor network. When the timing capacitor reaches the upper comparator threshold, the internal latch changes state and turns the discharge transistor ON. Pin 1 is then pulled close to ground while the capacitor discharges. When the lower trigger threshold is reached, the latch changes state again and the transistor switches OFF.

**Observed:**

- Vmin ≈ **−80 mV**
- Vmax ≈ **5.12 V**
- Vpp ≈ **5.20 V**
- square switching waveform at the astable rate

The observed switching confirms that the Timer 1 discharge transistor is alternately conducting and releasing the external timing network as expected.

**Pin 1 is behaving correctly.**

---

### Pin 2 — THRESHOLD1

**What it does:** Pin 2 is Timer 1's threshold input. Internally it feeds the upper comparator, which compares the external timing-node voltage with the upper reference generated by the timer's internal resistor divider, approximately two-thirds of VCC.

**What is connected to it:** Pin 2 is joined directly to pin 6 and to the Timer 1 timing capacitor.

**Expected:** A repeating charge/discharge waveform moving between approximately one-third and two-thirds of VCC.

**Why:** The timing capacitor charges until the threshold comparator detects that the node has reached approximately two-thirds of VCC. That comparator changes the internal latch state, which turns on the discharge transistor. The capacitor then discharges until the lower trigger comparator detects approximately one-third of VCC and reverses the latch state again.

**Observed:**

- Vmin ≈ **1.750 V**
- Vmax ≈ **3.370 V**
- Vpp ≈ **1.620 V**
- repeating ramp waveform

The measured limits closely match the expected one-third and two-thirds VCC switching region for a nominal 5 V supply.

**Pin 2 is behaving correctly.**

---

### Pin 3 — CONTROL1

**What it does:** Pin 3 exposes Timer 1's internal control-voltage node. This node is associated with the upper comparator reference generated by the internal three-resistor divider and therefore normally sits at approximately two-thirds of VCC.

**What is connected to it:** No external control source is used in the present Athena clock configuration.

**Expected:** An essentially steady DC level near two-thirds of VCC, approximately 3.3 V on a 5 V supply.

**Why:** With no external modulation applied, the internal resistor divider establishes the comparator reference. Unlike the timing node, this voltage is not intended to ramp during normal astable operation.

**Observed:**

- Vmin ≈ **3.290 V**
- Vmax ≈ **3.370 V**
- Vpp ≈ **80 mV**
- essentially flat trace

The measured level is consistent with the expected internal two-thirds-VCC control reference.

**Pin 3 is behaving correctly.**

---

### Pin 4 — RESET1

**What it does:** Pin 4 is the active-LOW reset input for Timer 1. Pulling this pin LOW overrides normal timer operation and forces the internal latch into the reset condition.

**What is connected to it:** Pin 4 is tied to +5 V so that Timer 1 remains enabled continuously.

**Expected:** A steady HIGH level.

**Why:** Because RESET is active LOW, holding this input HIGH permits the trigger comparator, threshold comparator, latch, discharge transistor and output stage to operate normally.

**Observed:** The trace remained firmly HIGH. Scope automatic measurements were approximately Vmin **5.40 V**, Vmax **6.00 V**, Vpp **600 mV**.

Functionally the reset input is held continuously inactive, as required for the astable oscillator.

**Pin 4 is behaving correctly.**

---

### Pin 5 — OUTPUT1

**What it does:** Pin 5 is the output of Timer 1. Internally the output driver follows the state established by the timer's SR latch, producing the digital clock waveform generated by the astable timing cycle.

**What is connected to it:** Pin 5 is the free-running astable clock output and feeds the astable input of the SN74LS157 clock selector. An indicator LED is also associated with the astable output in the breadboard clock.

**Expected:** A square waveform with abrupt LOW and HIGH transitions.

**Why:** The timing capacitor voltage itself is analogue and ramps between the two comparator thresholds, but the comparator/latch/output chain converts those threshold crossings into a two-state digital output. Each change of latch state therefore produces a sharp transition at pin 5.

**Observed:**

- Vmin ≈ **−80 mV**
- Vmax ≈ **3.640 V**
- Vpp ≈ **3.720 V**
- square-wave output

The measured HIGH level is below VCC, which is normal for the bipolar timer output stage under load, and remains a valid TTL HIGH level.

**Pin 5 is behaving correctly.**

---

### Pin 6 — TRIGGER1

**What it does:** Pin 6 is Timer 1's trigger input. Internally it feeds the lower comparator, which compares the timing-node voltage with the lower reference generated by the internal divider, approximately one-third of VCC.

**What is connected to it:** Pin 6 is joined directly to pin 2 and to the Timer 1 timing capacitor.

**Expected:** The same charge/discharge waveform seen on pin 2, because both pins are connected to the same physical timing node.

**Why:** During discharge, when the capacitor falls below approximately one-third of VCC, the trigger comparator changes state and sets the internal latch. That turns the discharge transistor OFF and begins the next charging interval.

**Observed:**

- Vmin ≈ **1.760 V**
- Vmax ≈ **3.320 V**
- Vpp ≈ **1.560 V**
- repeating ramp waveform matching the pin-2 timing-node behaviour

The observed lower and upper levels are consistent with the same timing capacitor node measured at pin 2.

**Pin 6 is behaving correctly.**

---

### Pin 7 — GND

**What it does:** Pin 7 is the common ground reference for both timers inside the dual 556.

**What is connected to it:** Pin 7 is connected to the breadboard ground rail.

**Expected:** A steady level at approximately 0 V.

**Why:** The internal comparators, resistor-divider references, latches, discharge transistors and output stages all operate relative to this ground reference.

**Observed:** Approximately **160 mV** with no visible switching component in the recorded capture.

**Pin 7 is behaving correctly.**

---

### Pin 8 — TRIGGER2

**What it does:** Pin 8 is the trigger input of Timer 2. Internally it feeds the lower trigger comparator, which compares the external trigger voltage with the lower internal reference, approximately one-third of VCC.

**What is connected to it:** In the current circuit, pin 8 is driven by **CD40106B pin 4**. The mechanical STEP switch acts on an RC node at CD40106B pin 1 (47 kΩ to +5 V, 100 nF to GND, and 1 kΩ in series with the switch to GND). Two Schmitt inverter stages condition the transition before it reaches pin 8. The earlier direct 10 kΩ pull-up and switch connection is retained below as historical verification evidence, but is no longer the current wiring.

#### STEP button released

**Expected:** Pin 8 should remain HIGH, close to +5 V.

**Why:** With pin 8 above the internal one-third-VCC trigger threshold, the trigger comparator does not set the internal SR latch. Timer 2 therefore remains in its stable state: pin 9 is LOW, the discharge transistor is active, and the timing network is ready for the next trigger. The current CD40106B output actively defines the trigger input. In the earlier direct-switch configuration, the 10 kΩ pull-up prevented the trigger input from floating.

**Observed:**

- Vmin ≈ **4.72 V**
- Vmax ≈ **5.04 V**
- Vpp ≈ **320 mV**
- essentially flat trace at about +5 V

The trigger input is safely above the internal lower comparator threshold.

**Pin 8 is behaving correctly in the idle state.**

#### STEP button pressed

**Expected:** Pin 8 should fall sharply from about +5 V to approximately 0 V and return HIGH when the button is released.

**Why:** Pressing STEP connects pin 8 directly to ground. Once the voltage falls below approximately one-third of VCC, the trigger comparator sets the internal SR latch. Setting the latch drives pin 9 HIGH and turns OFF Timer 2's discharge transistor, allowing the timing capacitor to begin charging through the external timing resistor. This is the event that starts the monostable interval.

**Observed:**

- HIGH level ≈ **5.2 V**
- LOW level ≈ **0 V**
- Vpp ≈ **5.44 V**
- clean HIGH → LOW → HIGH trigger excursion

The waveform crosses the internal trigger threshold decisively and produces the intended active-LOW trigger.

**Pin 8 is behaving correctly when triggered.**

---

### Pin 9 — OUTPUT2

**What it does:** Pin 9 is the output of Timer 2. Internally it is driven from the state of the Timer 2 SR latch through the output driver. In Athena this is the manual single-step clock pulse.

**What is connected to it:** Pin 9 feeds the manual-clock input of the SN74LS157 selector.

#### Idle state

**Expected:** Pin 9 should remain LOW while Timer 2 waits for a trigger.

**Why:** Before a trigger, the internal SR latch is in its stable reset state. The output driver therefore holds pin 9 LOW, while the discharge transistor keeps the monostable timing capacitor discharged and ready for the next event.

**Observed:**

- Vmin ≈ **−240 mV**
- Vmax ≈ **+160 mV**
- Vpp ≈ **400 mV**
- trace essentially flat around 0 V

The output is firmly within the LOW state.

**Pin 9 is behaving correctly in the idle state.**

#### Triggered state

**Expected:** Pulling pin 8 below approximately one-third of VCC should cause pin 9 to switch HIGH, remain HIGH for the monostable timing interval, and then return LOW automatically.

**Why:** The pin-8 trigger comparator sets the Timer 2 SR latch. That causes two linked internal changes: the output driver takes pin 9 HIGH, and the discharge transistor turns OFF so the external timing capacitor can charge. The timer remains in this state even after the STEP button is released.

As the timing capacitor charges, the threshold comparator monitors the timing node. When that voltage reaches approximately two-thirds of VCC, the threshold comparator resets the SR latch. The output driver then returns pin 9 LOW and the discharge transistor turns ON again, discharging the timing capacitor and restoring the stable state.

**Observed:**

- LOW level ≈ **0 V**
- HIGH level ≈ **4.32 V**
- Vpp ≈ **4.64 V**
- distinct HIGH pulses produced for successive STEP presses
- each pulse returns automatically to LOW
- a small transient overshoot is visible at the switching edges

The brief overshoot has not yet been isolated between the 556 output transition itself and the oscilloscope probing arrangement. It does not alter the valid steady TTL logic levels.

The pulse duration has not yet been recorded as a precise verified measurement in this journal.

The behaviour confirms that the trigger comparator, internal latch, discharge control, threshold path and output stage are operating together as a monostable.

**Pin 9 is behaving correctly when triggered.**

---

### Pin 10 — RESET2

**What it does:** Pin 10 is the active-LOW reset input for Timer 2. Internally RESET provides a direct override of the timer's SR latch. When driven LOW it forces the latch into the reset state regardless of the trigger and threshold comparators, driving the output LOW and preventing the monostable timing sequence. When held HIGH, that override is removed.

**What is connected to it:** Pin 10 is tied directly to +5 V so that Timer 2 remains enabled during normal operation.

**Expected:** A steady HIGH level close to VCC.

**Why:** Holding RESET HIGH allows Timer 2 to respond normally to the LOW-going trigger on pin 8 and to terminate the monostable interval when the threshold comparator detects the timing node reaching the upper reference.

**Observed:**

- Vmin ≈ **4.72 V**
- Vmax ≈ **5.04 V**
- Vpp ≈ **320 mV**
- trace essentially flat at about +5 V

The reset override is inactive and Timer 2 is enabled to operate normally.

**Pin 10 is behaving correctly.**

---

### Pin 11 — CONTROL2

**What it does:** Pin 11 is the control-voltage input for Timer 2. Internally it exposes the upper control/reference node associated with the timer's resistor-divider network and the threshold comparator reference, nominally near two-thirds of VCC.

**What is connected to it:** Pin 11 is externally unconnected in the current circuit. It is not electrically floating internally because the 556's internal divider biases the node. A small bypass capacitor may optionally be fitted to ground for noise reduction.

**Expected:** A nearly steady voltage around two-thirds of VCC, approximately 3.3 V for a nominal 5 V supply.

**Why:** With no external control voltage applied, the internal divider establishes the control/reference level. Unlike the timing node, this point should not show the monostable charging ramp.

**Observed:**

- approximately **3.0–3.3 V**
- essentially flat trace

The measured level is consistent with the internally generated upper control/reference voltage.

**Pin 11 is behaving correctly.**

---

### Pin 12 — THRESHOLD2

**What it does:** Pin 12 is the threshold input for Timer 2. Internally it feeds the threshold comparator, which compares the timing-node voltage against the upper reference generated by the 556's internal divider, approximately two-thirds of VCC.

With a 5 V supply, that reference is approximately:

`(2/3) × 5 V ≈ 3.3 V`

When the voltage on pin 12 reaches this level, the threshold comparator resets the internal SR latch. That ends the monostable pulse, drives pin 9 LOW and turns the discharge transistor back ON.

**What is connected to it:** Pin 12 is tied externally to pin 13 at the monostable timing node. That node is connected to **1 MΩ** to +5 V and a **1 µF** timing capacitor to GND.

#### Idle state

**Expected:** Pin 12 should sit close to 0 V.

**Why:** In the stable state, the internal discharge transistor is conducting through pin 13. Because pins 12 and 13 are tied together externally, that transistor holds the timing capacitor discharged and keeps the threshold input well below the upper trip level.

**Observed:**

- Vmin ≈ **−160 mV**
- Vmax ≈ **+80 mV**
- Vpp ≈ **240 mV**
- trace essentially flat around 0 V

The timing node is being held discharged as expected.

**Pin 12 is behaving correctly at rest.**

#### Triggered state

**Expected:** When pin 8 is pulled LOW, the trigger comparator sets the internal SR latch. The discharge transistor then turns OFF, allowing the 1 µF timing capacitor to charge through the 1 MΩ resistor. Pin 12 should therefore show a rising exponential voltage from near 0 V towards approximately two-thirds of VCC. When the threshold is reached, the threshold comparator should reset the latch, causing the discharge transistor to turn ON and rapidly discharge the timing capacitor back towards ground.

**Observed:**

- Vmin ≈ **−160 mV**
- Vmax ≈ **3.20 V**
- Vpp ≈ **3.36 V**
- clear rising charging curve
- abrupt return to approximately 0 V

The measured peak of about 3.2 V is consistent with the expected upper threshold region for a nominal 5 V supply.

The waveform directly shows the monostable timing sequence: the timing capacitor charges while the discharge transistor is OFF, the threshold comparator detects the upper reference, the latch resets, and the discharge transistor rapidly returns the timing node to ground.

**Pin 12 is behaving correctly when triggered.**

---

## Remaining pins

Pins 13 and 14 remain to be documented in the same format. The next measurement is pin 13 (DISCHARGE2).

## Evidence handling

Scope captures corresponding to these measurements should be stored under:

`evidence/oscilloscope/clock/`

Once the original image files are added, each pin entry should link directly to its supporting capture rather than relying on chat history.

## 19 September 2026 — STEP debounce verification

### Purpose

Determine why manual STEP operation sometimes produced more than one CPU clock event, implement a hardware correction based on the measured failure mechanism, and verify the correction at both the 556 trigger input and the final CPU clock.

### Pre-correction observation

DSLogic captures showed multiple short clock transitions associated with individual intended STEP actions. Oscilloscope measurements traced the disturbance backwards to 556 pin 8, where several rapid HIGH/LOW transitions were visible around a switch press.

Replacing the original switch with a 6 mm tactile switch reduced the problem substantially but did not eliminate it; a retained capture still showed an additional short CPU-clock pulse.

### Implemented conditioning

A CD40106BE Schmitt-trigger inverter was added with:

- pin 1 → 47 kΩ → +5 V;
- pin 1 → 100 nF → GND;
- pin 1 → 1 kΩ → STEP switch → GND;
- pin 2 → pin 3;
- pin 4 → 556 pin 8.

Two inverter stages preserve the original active-LOW trigger polarity.

### Oscilloscope result

Dual-channel observation used:

- yellow: CD40106B pin 1, the RC node;
- blue: 556 pin 8, the conditioned trigger.

Observed:

- the RC node transitions between defined HIGH and LOW levels;
- the 556 trigger changes cleanly from HIGH to LOW;
- no visible contact chatter remains at pin 8 at the test timebase.

This verifies the local electrical function of the debounce stage.

### Logic-analyser result

A retained post-debounce DSLogic capture showed deliberate manual STEP actions producing one clean CPU clock pulse each, with no additional short chatter pulses.

**Observed fact:** the implemented RC + CD40106B stage removed the previously visible repeated CPU-clock events in the captured test.

**Acceptance result:** manual STEP input debouncing and clean single-clock generation are verified for the tested configuration.

## 19 September 2026 — RUN/MANUAL propagation recheck

An apparent transient observation suggested that a manual STEP might be propagating while RUN was selected. The clock path was therefore checked stage by stage.

Measured:

- SN74LS157 pin 1 SELECT: **0 V in MANUAL**, approximately **3.6 V in RUN**;
- SN74LS157 pin 4 selected-clock output: no STEP-correlated change in RUN;
- SN7400 pin 9: no STEP-correlated change in RUN;
- SN7400 pin 11 final CPU clock: no STEP-correlated change in RUN.

**Conclusion:** the current selector and final clock-gating path reject the manual STEP source correctly in RUN mode. The earlier observation could not be reproduced after the temporary test wiring had been stabilised.

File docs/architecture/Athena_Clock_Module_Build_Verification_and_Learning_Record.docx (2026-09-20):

ATHENA

# Clock Module Build, Verification and Learning Record

From 555/556 timing experiments to a selectable, gated CPU clock

Current status: core clock architecture functionally verified

Repository baseline and bench evidence consolidated to 19 September 2026

Scope note

Later Z80-specific frequency and clock-level adaptations are recorded separately from the original module design.

# 1. Purpose and scope

This document records the design, construction, testing, fault-finding and learning associated with the Athena clock module. The clock began as a practical exploration of 555-family timing behaviour and developed into a complete CPU clock subsystem with variable-speed RUN operation, manual single-step operation, persistent RUN/MANUAL mode selection, HLT gating and an observable final CPU clock.

The record deliberately separates the original clock-module architecture from later changes made only to interface that module to the 1986 NMOS Z80. It also separates confirmed bench evidence from repository baselines, deductions and items still marked for verification.

# 2. Executive summary

- The original learning work established astable, monostable and latch behaviour using 555-family circuits before the design was consolidated around one NE556 dual timer.
- U1A (NE556 Timer 1) generates the variable-speed astable RUN clock.
- U1B (NE556 Timer 2) generates the manual STEP pulse.
- Two gates of a SN7400 form a cross-coupled RUN/MANUAL latch; its Q output drives the selector.
- One channel of a SN74LS157 selects either the STEP pulse or the astable clock.
- The remaining SN7400 gates implement HLT gating and produce the final CPU_CLK on SN7400 pin 11.
- The NE556 was systematically verified by oscilloscope, including its threshold ramps, outputs, trigger behaviour and monostable timing node.
- A major monostable fault was traced to a ~1 kΩ resistor fitted where 1 MΩ was required. Correcting the resistor restored the expected exponential timing ramp.
- A later end-to-end fault was traced to SN7400 pin 9 still being wired directly to NE556 pin 5, bypassing the SN74LS157 selector. Removing that legacy connection and routing SN74LS157 pin 4 to SN7400 pin 9 restored correct RUN/MANUAL operation.
- RUN, MANUAL, STEP and HLT behaviour were then functionally verified at the final CPU clock output.
- 19 September: the STEP RC/Schmitt stage removed the observed trigger chatter, and RUN-mode propagation rejected STEP at every tested stage. The final clock at Z80 pin 6 measured approximately 270.407 kHz.
- Manual STEP is now conditioned by a CD40106BE: the retained 19 September capture showed one clean CPU_CLK pulse per deliberate press. This enables controlled clock/T-state investigation, subject to the connected CPU’s timing limits; reliable hand-stepped execution of the NMOS Z80 is not established.
- For Z80 bring-up, the astable timing capacitor was later changed to 470 pF and a separate 330 Ω pull-up was added at the Z80 clock input. Those are interface/operating-range adaptations, not silent changes to the original schematic baseline.

# 3. Design evolution

The clock work grew directly from the Ben Eater eight-bit computer learning sequence. The earlier 555-based experiments were not discarded; they established the physical meaning of the 1/3 VCC and 2/3 VCC thresholds, the discharge transistor, astable charging/discharging, monostable triggering and the distinction between an oscillator, a one-shot and a stored logic state.

The current Athena design separates input conditioning, clock generation, stored mode, source selection, gating and output. It retains the Ben Eater learning objectives while using an NE556, TTL NAND logic, a dedicated multiplexer and, from 19 September, CD40106BE Schmitt conditioning.

Stage | Implementation | Learning/architectural role
Foundation | Individual 555-family experiments | Understand timing thresholds, discharge switching, astable and monostable behaviour.
Consolidation | NE556 dual timer | Place astable and manual pulse generation in one IC while preserving observability.
Mode memory | SN7400 cross-coupled NAND latch | Store RUN versus MANUAL as a persistent logic state.
Selection | SN74LS157 | Choose one of the two clock sources cleanly from the stored state.
Gating/output | SN7400 gates 3 and 4 | Permit or block the selected clock under HLT control and provide CPU_CLK.

# 4. Architecture and signal flow

Manual path: STEP → CD40106BE RC/Schmitt conditioning → NE556 Timer 2. RUN path: NE556 Timer 1. Both sources feed SN74LS157 → SN7400 HLT gating → CPU_CLK; the SN7400 latch controls the selector.

This decomposition is central to the learning value of the module. Each stage can be probed independently, and a fault can be localised to generation, stored mode, selection or final gating rather than treating the clock as a black box.

## 4.1 Functional roles of the three original ICs

IC | Device | Function in Athena
U1 | NE556 / RS 305-838 | Timer 1 produces the variable astable clock; Timer 2 produces the manual STEP pulse.
U2 | TI SN7400 | Gates 1/2 form the RUN/MANUAL latch; gates 3/4 implement HLT gating and final clock output.
U3 | TI SN74LS157N | Quad 2:1 multiplexer; channel 1 selects MANUAL or ASTABLE under control of U2 pin 6 (Q).

## 4.2 U4: CD40106BE input conditioning — 19 September 2026

A fourth IC now conditions STEP before NE556 Timer 2. Two Schmitt inverters preserve the original active-LOW polarity. The RC node is directly observable at pin 1 and the conditioned trigger at NE556 pin 8.

# 5. KiCad schematic baseline

The repository contains the Athena KiCad project at hardware/kicad/Athena/Athena.kicad_pro, with Clock.kicad_sch as the hierarchical clock sheet and hardware/kicad/Athena/exports/Athena-clock.pdf as the exported A3 schematic. The project record identifies KiCad 10.0.3 on macOS.

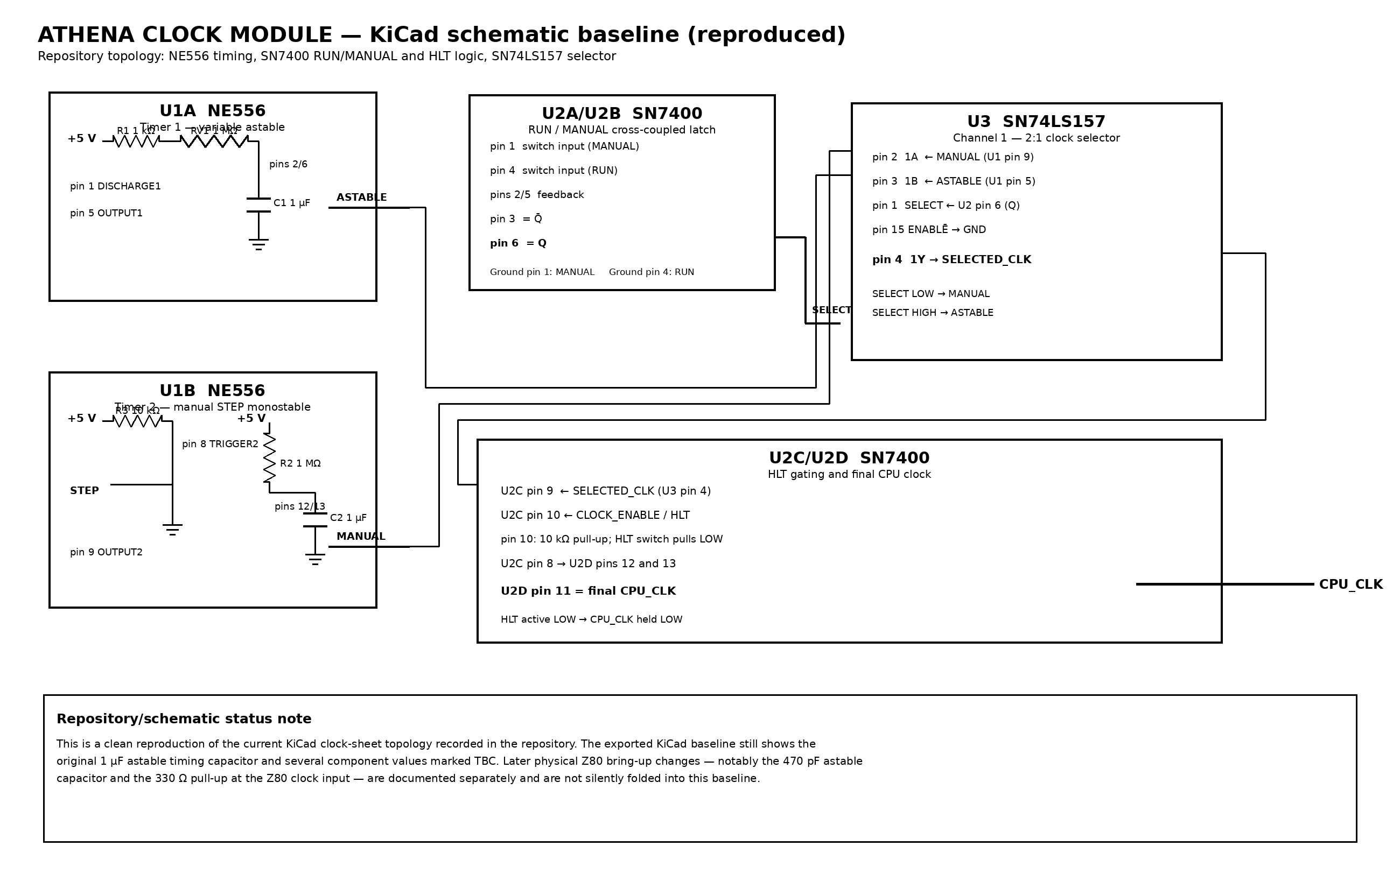
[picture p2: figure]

Figure 1. Historical KiCad clock-sheet topology before the 19 September debounce addition; retained as baseline evidence.

Historical repository status: ERC was recorded as 0 errors and 1 warning for the earlier schematic; the warning concerned CPU_CLK at the module boundary. This is not an ERC result for the current debounce circuitry.

Important limitation: The KiCad baseline still shows the original 1 µF astable timing capacitor and several component values marked TBC. Later physical Z80 bring-up changes are therefore documented separately rather than silently presented as if already incorporated into the schematic.

## 5.1 KiCad items still marked TBC or provisional

- RUN/MANUAL pull-up resistor values R4 and R5 were not yet confirmed in the schematic record.
- HLT and astable LED resistor values R7 and R8 remain to be confirmed.
- D2 is associated with the astable signal, but its complete LED wiring/polarity record was still provisional.
- The unused end of RV1 is drawn open; the physical breadboard should be checked to confirm whether it is strapped to the wiper.
- The physical terminal numbering/type of the RUN/MANUAL switch SW2 remains to be documented exactly.
- Local bypass capacitors C3, C4 and C5 are provisions in the drawing; fitted presence/values require confirmation.
- Unused SN74LS157 data inputs are intended to be held at a defined logic level; the current breadboard should be checked before the schematic is promoted to definitive as-built status.

## 5.2 Current schematic limitation — 19 September 2026

Documented discrepancy: At repository commit ffd4e58, the debounce symbols and wiring are appended after the closing main structure in Clock.kicad_sch. A KiCad 10.0.3 export of Athena.kicad_sch omits U4, R9 and C6. The appended symbols also retain U1 reference properties and rel_osc instance labels. The claimed schematic update therefore does not yet form a usable as-built circuit.

Figure 1 and the existing ERC/export remain historical. The verified breadboard connections in section 7.4 take precedence for the debounce build; the schematic needs repair and a fresh connectivity check.

# 6. U1A: variable-speed astable generator

Timer 1 of the NE556 is wired as an astable oscillator. The timing capacitor repeatedly charges and discharges between the internal approximately 1/3 VCC and 2/3 VCC comparator thresholds. The output at pin 5 changes state as the internal latch responds to those threshold crossings.

## 6.1 Baseline timing network

The repository baseline uses +5 V → 1 kΩ fixed resistor → pin 1 (DISCHARGE1) → 1 MΩ variable resistor → joined pins 2/6 → timing capacitor → GND. The original KiCad baseline shows a 1 µF timing capacitor.

## 6.2 Oscilloscope verification

Pin | Function | Observed | Interpretation
1 | DISCHARGE1 | Vmin ≈ -80 mV; Vmax ≈ 5.12 V; Vpp ≈ 5.20 V; switching waveform | Discharge path is switching as the astable cycle changes state.
2 | THRESHOLD1 | Vmin ≈ 1.750 V; Vmax ≈ 3.370 V; Vpp ≈ 1.620 V; ramp | Timing node traverses the expected ~1/3 to ~2/3 VCC region.
3 | CONTROL1 | ≈3.29-3.37 V; ~80 mV variation | Internal control reference sits near 2/3 VCC.
4 | RESET1 | Held HIGH | Timer 1 reset is inactive; oscillator permitted to run.
5 | OUTPUT1 | Vmin ≈ -80 mV; Vmax ≈ 3.64 V; Vpp ≈ 3.72 V; square wave | Valid TTL-like astable source presented to the selector.
6 | TRIGGER1 | Vmin ≈ 1.76 V; Vmax ≈ 3.32 V; Vpp ≈ 1.56 V; ramp | Same timing node behaviour as pin 2, consistent with joined trigger/threshold node.
7 | GND | Near ground; no switching function expected | Common 0 V reference.

# 7. U1B: manual STEP monostable

Historical direct-switch configuration: Timer 2’s trigger was held HIGH through 10 kΩ and STEP pulled NE556 pin 8 LOW directly. From 19 September, CD40106BE pin 4 drives pin 8 instead; the former pull-up/direct-switch connection is superseded. The monostable mechanism remains: the trigger comparator sets the latch, the discharge transistor releases the timing node, the capacitor charges through 1 MΩ, and the threshold comparator ends the pulse.

## 7.1 Historical trigger and output measurements

Pin | Function | Observed | Interpretation
8 | TRIGGER2 | Idle ≈4.72-5.04 V; pressed transition to ~0 V; Vpp ≈5.44 V | STEP button provides the required active-LOW trigger.
9 | OUTPUT2 | Steady LOW ≈0 V; HIGH ≈4.32 V; edge overshoot observed | Manual one-shot output is present and suitable as the selector's A input.
12 | THRESHOLD2 timing node | After correction: exponential rise with peak around 3.20 V, then rapid return near 0 V | Correct monostable RC timing behaviour restored.
13 | DISCHARGE2 timing node | Externally the same RC node as pin 12 | Internal discharge transistor controls the rapid return to ground.

## 7.2 Major fault: wrong Timer 2 timing resistor

Expected: A 1 MΩ resistor from the Timer 2 timing node to +5 V, with a 1 µF capacitor, giving a human-visible monostable interval.

Observed: The fitted resistor measured approximately 0.9943 kΩ, about 994 Ω.

Causal chain: Using ~1 kΩ instead of 1 MΩ shortened the RC time constant by roughly 1000×. With 1 µF, the pulse was around the millisecond scale, so on the previous slow oscilloscope timebase the capacitor charge looked almost instantaneous and the node appeared misleadingly square-like.

Correction: The ~1 kΩ part was replaced with 1 MΩ.

Result: The expected exponential pin-12 charging ramp appeared immediately, peaking around 3.20 V before rapid discharge.

Learning: When a timing waveform contradicts the model, verify the physical R and C values and node connectivity before inventing a more complicated explanation.

## 7.3 STEP chatter diagnosis — 19 September 2026

DSLogic showed multiple unintended CPU-clock transitions during manual stepping. Scope tracing moved backwards through the clock path: disturbance was observed at NE556 pin 9, then chatter directly at pin 8. This located an input disturbance upstream of the monostable output rather than merely inferring a downstream selector fault.

A hand-held jumper was an imperfect switch-bypass diagnostic because hand movement itself introduced chatter. Replacing the original switch with a better 6 mm tactile switch made the waveform substantially cleaner, but the retained analyser test still showed an unwanted additional short pulse. Mechanical switch quality alone did not establish single-clock operation.

Deduction: Hardware conditioning was required. The CD40106BE solution was selected from available stock and derived from measurement and deduction from the observed fault; it was not copied from an existing Z80 clock design.

### Alternatives investigated

CD4093BE Schmitt NAND logic; comparator hysteresis using LM393, HA17393 or AN1319; an SN7400 NAND SR latch with an SPDT momentary switch; 74LS123 monostable conditioning; flip-flop approaches; and modification of the existing 556 trigger network were considered. These expose distinct mechanisms—hysteresis, state memory and pulse shaping—and remain meaningful possible experiments. They are not recorded as built or verified alternatives.

## 7.4 Current as-built CD40106BE STEP network

- Pin 14 → +5 V.
- Pin 7 → GND.
- Pin 1 → 47 kΩ → +5 V.
- Pin 1 → 100 nF → GND.
- Pin 1 → 1 kΩ → normally-open STEP switch → GND.
- Pin 2 → pin 3.
- Pin 4 → NE556 pin 8.
- Unused inputs, pins 5, 9, 11 and 13, are held at defined levels; the confirmed build record specifies GND.
- Unused outputs, pins 6, 8, 10 and 12, are unconnected.
- The former direct 10 kΩ pull-up / STEP-switch connection at NE556 pin 8 is superseded.

The capacitor charges through 47 kΩ when the switch is open and discharges through the switched 1 kΩ path when pressed. The first inverter uses different rising and falling thresholds; its hysteresis prevents small RC-node reversals from repeatedly changing the output. The second inverter restores HIGH at rest and LOW on STEP. Exact switching thresholds and delay were not measured in this session.

## 7.5 Local scope verification

### CD40106BE pin 1 — STEP RC input

What it does: Feeds the first inverter’s internal hysteretic switching stage.

What is connected to it: 47 kΩ to +5 V, 100 nF to GND and 1 kΩ through the normally-open STEP switch to GND.

Expected: An analogue fall on pressing STEP and recovery towards HIGH on release.

Why: The capacitor stores charge and the resistor paths limit its rate of change; the Schmitt stage switches at distinct directional thresholds.

Observed: The yellow scope channel monitored pin 1 and showed the expected analogue transition. Exact voltage extrema and delay are not established.

Conclusion: The RC input responded as expected in the captured test.

### NE556 pin 8 — TRIGGER2 — conditioned STEP input

What it does: The trigger comparator sets Timer 2’s latch when the input falls below its lower reference.

What is connected to it: CD40106BE pin 4, after two Schmitt inversions.

Expected: HIGH at rest and one clean LOW-going trigger on a deliberate press.

Why: The second inverter restores the active-LOW polarity; the 556 then produces the monostable pulse using its own timing network.

Observed: The blue channel monitored pin 8 alongside the pin-1 RC trace. Pin 8 changed cleanly with no visible chatter at the test timebase. The resting HIGH polarity was confirmed; no new exact voltage extrema were established.

Conclusion: Pin 8 is behaving correctly for the tested conditioned STEP event. The earlier section 7.1 measurements remain evidence for the superseded direct-switch configuration.

Released state: the charged RC node produces LOW at CD40106BE pin 2 and HIGH at pin 4, leaving the 556 trigger inactive. Pressed state: the RC voltage falls, pin 2 becomes HIGH and pin 4 LOW, allowing the trigger comparator to start the monostable. These state explanations are deductions from the verified wiring; they do not introduce additional measured values.

# 8. U2A/U2B: RUN/MANUAL state latch

SN7400 gates 1 and 2 are cross-coupled to form a bistable NAND latch. Unlike the two NE556 sections, this part does not generate time. It stores the selected operating mode.

SN7400 pin | Role
1 | Gate 1 switch input; normally HIGH, grounded to select MANUAL according to the schematic convention.
2 | Feedback from pin 6 (Q).
3 | Gate 1 output, Q̄; feeds pin 5.
4 | Gate 2 switch input; normally HIGH, grounded to select RUN according to the schematic convention.
5 | Feedback from pin 3 (Q̄).
6 | Gate 2 output, Q; drives SN74LS157 SELECT pin 1.

The latch gives the switch action memory: after the appropriate input is asserted and released, the cross-coupled feedback keeps the selected state. This separates the act of choosing RUN or MANUAL from the clock waveforms themselves.
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

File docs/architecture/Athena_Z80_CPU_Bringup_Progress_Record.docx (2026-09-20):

ATHENA

# Z80 CPU Bring-up Progress, Evidence and Learning Record

From first clock interface to observable instruction execution

Current milestone: controlled NOP execution and bus observation

Prepared from the bench work completed to 19 September 2026

Status

Working CPU bring-up experiment; not yet a complete computer

# 1. Purpose and scope
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

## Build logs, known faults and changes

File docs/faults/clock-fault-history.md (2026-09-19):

# Athena Clock Module — Fault and Diagnostic History

Status: **historical engineering record**

This file records faults, diagnostic dead ends, damaged parts, wiring errors and corrective reasoning associated with the Athena clock work. The purpose is to preserve what was learned rather than merely documenting the final working state.

## PSU over-voltage incident

A major earlier failure occurred when a bench PSU memory button adjacent to the power control was pressed unintentionally. The stored setting applied approximately **30 V at a 5 A current limit** to a TTL breadboard intended for roughly 5 V operation.

Observed consequence: multiple devices failed or were suspected damaged, including logic used in the earlier clock implementation.

Engineering significance:

- TTL parts must never be exposed to supply voltages remotely close to 30 V.
- Current limiting does not protect logic from destructive over-voltage if the limit is still far above the device's normal operating current.
- Bench-supply stored presets are an operational hazard when their controls can be confused with power controls.
- After such an event, subsequent faults must not be diagnosed under the assumption that every previously fitted IC remains healthy.

This incident is part of the clock's history but is not representative of the current verified 556/SN7400/SN74LS157 build.

## Floating RESET on earlier timer build

An earlier 555-based build had RESET left floating.

Diagnosis: a floating asynchronous control input can produce unpredictable operation because its logic level is not defined.

Correction: RESET was tied to the required inactive HIGH state.

Lesson retained in the current 556 implementation: both reset inputs used for normal operation are deliberately held HIGH.

## Earlier monostable wiring problems

During the earlier 555/556 learning work, the monostable output showed incorrect behaviour when the trigger and timing network were miswired. Symptoms included stuck indicator states and unexpected output polarity/levels.

The diagnostic method developed from this was to separate the trigger node from the rest of the switch wiring and verify the electrical requirements directly:

1. establish a defined idle level;
2. force the trigger state manually;
3. measure the trigger pin itself;
4. only then reintroduce the mechanical switch.

This method was reused successfully in the current pin-8 verification.

## STEP switch diagnosis — current 556 build

### Symptom

The STEP trigger initially behaved with the wrong polarity when the push-button wiring was introduced. Pin 8 could appear LOW at rest and HIGH on button action, contrary to the intended active-LOW trigger arrangement.

### Isolation

The switch was removed from the reasoning path and pin 8 was reduced to the simplest possible circuit:

- pin 8 connected to VCC through 10 kΩ;
- nothing else connected to pin 8.

Measured result: pin 8 was HIGH.

A jumper was then used to connect pin 8 directly to GND.

Measured result: pin 8 went LOW.

This verified the pull-up and trigger node independently of the switch.

### Switch correction

The STEP control was then wired so that:

- released = pin 8 HIGH;
- pressed = pin 8 connected to GND and therefore LOW.

Scope verification confirmed the intended HIGH → LOW → HIGH trigger waveform.

### Lesson

The important diagnostic result was not merely the final wiring. The trigger input was proved independently before the switch was treated as part of the circuit. This prevented a mechanical-contact assumption from being mistaken for an IC fault.

## Timer 2 timing resistor error — pin 12 investigation

### Symptom

During systematic verification of Timer 2, pin 12 (THRESHOLD2) did not show the expected monostable timing-capacitor ramp. The trace appeared square-like rather than showing an exponential rise towards approximately two-thirds of VCC followed by rapid discharge.

Changing the timing capacitor from **1 µF to 10 µF** did not initially produce the expected visible ramp. Removing the capacitor also failed to produce behaviour consistent with the assumed 1 MΩ timing network.

### Isolation

With power removed, continuity checks established that the physical timing node was correctly connected:

- capacitor positive node → pin 12: continuity confirmed;
- capacitor positive node → pin 13: continuity confirmed.

The resistance from the joined pins-12/13 timing node to +5 V was then measured directly.

Expected: approximately **1 MΩ**.

Measured: approximately **0.9943 kΩ**, about **994 Ω**.

A roughly **1 kΩ** resistor had been fitted where the monostable required **1 MΩ**.

### Causal chain

With 1 kΩ and 1 µF:

`RC ≈ 1 ms`

and the nominal monostable interval is only about:

`1.1 × RC ≈ 1.1 ms`.

At the scope timebase previously in use, approximately **100 ms/div**, that charging interval was effectively instantaneous on screen and therefore appeared as a square transition rather than a visible capacitor ramp.

The incorrect resistor was replaced with **1 MΩ**.

The expected pin-12 waveform then appeared immediately:

- timing node near 0 V at rest;
- exponential rise after trigger;
- peak around **3.20 V**, consistent with the upper threshold region;
- rapid return to approximately 0 V when the threshold comparator reset the latch and the discharge transistor turned on.

### Lesson

When a measured waveform contradicts a well-established model, verify the physical component values and node connectivity before inventing a new explanation for the behaviour.

Informal reminder retained from the session: **“pay attention, Eddie!”**

## Breadboard-image interpretation caution

During diagnosis, visual inspection of photographs repeatedly risked introducing false assumptions about which rail or switch terminal was electrically connected.

Project rule established from this work:

**Every photograph is fresh evidence.**

A new photograph must be traced from visible endpoint to visible endpoint. Expected topology must not be substituted for what is actually visible. Where continuity cannot be established visually, it must be measured rather than guessed.

## Pin 9 switching overshoot

During triggered Timer 2 operation, the pin-9 output showed a small transient overshoot at switching edges.

Current status: **observed, not yet isolated**.

The steady output levels remain valid:

- LOW ≈ 0 V
- HIGH ≈ 4.32 V

Possible sources include the real 556 output edge, breadboard/interconnect parasitics, and oscilloscope probe-ground inductance. No fault has been assigned because the source has not yet been distinguished experimentally.

## Historical 555 implementation

The clock began as a Ben Eater-style implementation using individual 555 timers for astable, monostable and mode-control functions.

That work remains educationally relevant because it established:

- the astable timing-capacitor waveform;
- approximate one-third/two-thirds VCC thresholds;
- discharge-pin switching;
- manual monostable timing;
- the distinction between astable, monostable and bistable behaviour.

The individual-555 implementation has been superseded by the current dual-556 plus TTL/multiplexer architecture, but it should be archived rather than discarded.

## Status

No unresolved fault currently prevents continued systematic verification of the 556. Verification is complete through pin 12; the next measurement is pin 13 (DISCHARGE2).

## STEP contact chatter and Schmitt-trigger debounce — 19 September 2026

### Symptom

Logic-analyser captures made during manual stepping showed that a single intended STEP action could produce multiple CPU-clock transitions. This made the assumption "one button press = one Z80 T-state" unsafe.

### Isolation by measurement

The fault was traced backwards through the clock path rather than treated as a generic CPU problem.

Observed sequence:

1. DSLogic showed extra short CPU-clock events during manual stepping.
2. Oscilloscope probing confirmed that the disturbance was real rather than only a logic-analyser threshold artefact.
3. The disturbance was visible at 556 pin 9, the manual monostable output.
4. Probing 556 pin 8 showed several rapid HIGH/LOW transitions around a STEP action.
5. This established that the unwanted events were already present at the trigger input, upstream of the 556 timing function.

A hand-held jumper was considered as a bypass test, but hand movement itself introduced contact chatter and therefore was not a sufficiently controlled discriminator.

### Mechanical-switch comparison

The original STEP switch was replaced temporarily with a small 6 mm tactile momentary switch.

Result: the new switch was dramatically cleaner, but a retained DSLogic capture still contained at least one additional short clock event. The mechanical replacement therefore reduced the fault but did not provide the reliability required for CPU single-stepping.

### Deduction

The evidence supported the following causal model:

mechanical contact bounce → repeated/slow trigger transitions → repeated 556 trigger activity → additional manual clock events → unreliable Z80 T-state stepping.

The solution was therefore derived from the measured failure mechanism rather than copied from an existing computer design.

### Alternatives investigated

Before choosing the final implementation, the following hardware approaches were considered:

- CD40106BE Schmitt-trigger inverter with RC input filtering;
- CD4093BE Schmitt NAND logic;
- comparator-based hysteresis using LM393, HA17393 or AN1319;
- NAND SR-latch debouncing using an SPDT momentary switch;
- 74LS123 monostable conditioning;
- flip-flop-based conditioning;
- modification of the existing 556 trigger network.

The alternatives remain useful experiments, particularly the comparator approach because it would allow hysteresis thresholds to be calculated and measured directly.

### Implemented correction

A CD40106BE was added ahead of 556 pin 8.

Current network:

- CD40106B pin 1 → 47 kΩ → +5 V;
- CD40106B pin 1 → 100 nF → GND;
- CD40106B pin 1 → 1 kΩ → STEP switch → GND;
- CD40106B pin 2 → pin 3;
- CD40106B pin 4 → 556 pin 8;
- pin 14 → +5 V;
- pin 7 → GND;
- unused CMOS inputs tied to GND.

The previous direct 10 kΩ pull-up and mechanical switch connection at 556 pin 8 was removed.

### Verification

Oscilloscope observation showed:

- the CD40106B pin-1 RC node making a controlled HIGH-to-LOW transition;
- 556 pin 8 receiving a clean abrupt HIGH-to-LOW trigger with no visible chatter at the test timebase.

A subsequent retained DSLogic capture showed one clean CPU clock pulse per deliberate STEP action and no short chatter bursts.

### Selector-path recheck

An apparent later observation suggested that STEP might still be reaching the CPU while RUN was selected. Because extensive probing and temporary wiring had been taking place, the complete propagation path was rechecked.

Measured:

- SN74LS157 pin 1: 0 V in MANUAL, approximately 3.6 V in RUN;
- SN74LS157 pin 4: no STEP-correlated change in RUN;
- SN7400 pin 9: no STEP-correlated change in RUN;
- SN7400 pin 11: no STEP-correlated change in RUN.

The anomaly could not be reproduced. Current evidence supports correct source selection. The earlier observation is retained as a transient debugging/probing artefact rather than silently erased.

### Learning result

This fault is a useful Athena example of evidence-led design. The circuit was not "fixed" by replacing parts at random. The unwanted CPU behaviour was traced to its source, alternative explanations were eliminated, a conditioning mechanism appropriate to the observed analogue behaviour was selected, and the correction was verified both locally and at the final CPU clock.

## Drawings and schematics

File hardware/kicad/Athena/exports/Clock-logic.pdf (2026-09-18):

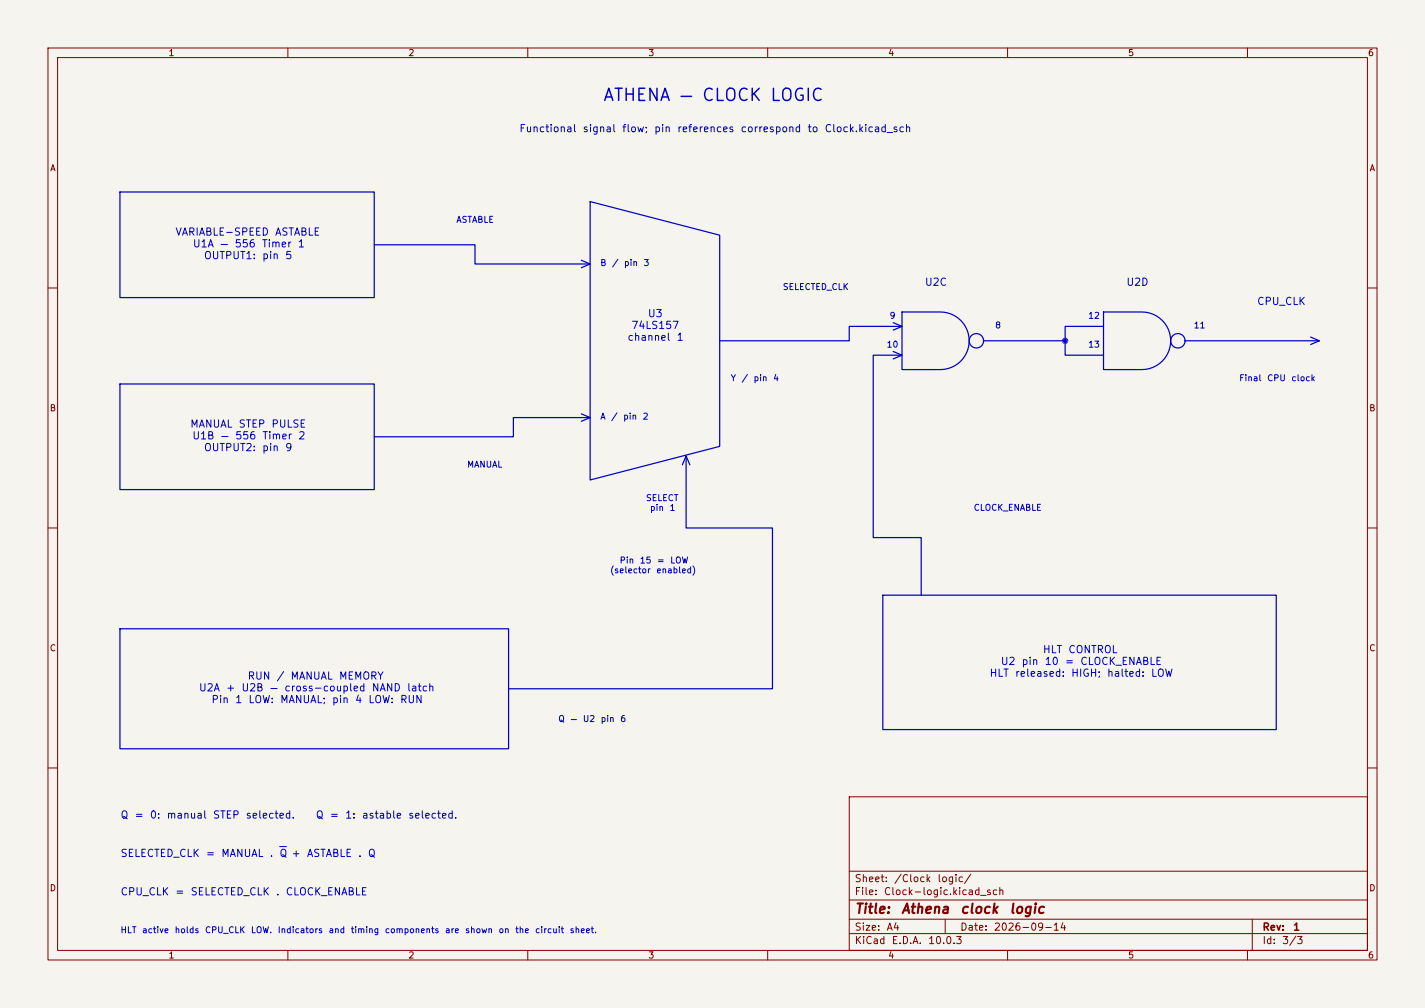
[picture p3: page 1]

Functional signal flow; pin references correspond to Clock.kicad_sch

MANUAL ASTABLE VARIABLE-SPEED ASTABLE

Final CPU clock RUN / MANUAL MEMORY

SELECT pin 1 Pin 15 = LOW

U2 pin 10 = CLOCK_ENABLE
HLT released: HIGH; halted: LOW

U2A + U2B — cross-coupled NAND latch
Pin 1 LOW: MANUAL; pin 4 LOW: RUN

Sheet: /Clock logic/
File: Clock-logic.kicad_sch
Title: Athena clock logic

HLT active holds CPU_CLK LOW. Indicators and timing components are shown on the circuit sheet.

Size: A4 | Rev: 1
KiCad E.D.A. 10.0.3 | Id: 3/3

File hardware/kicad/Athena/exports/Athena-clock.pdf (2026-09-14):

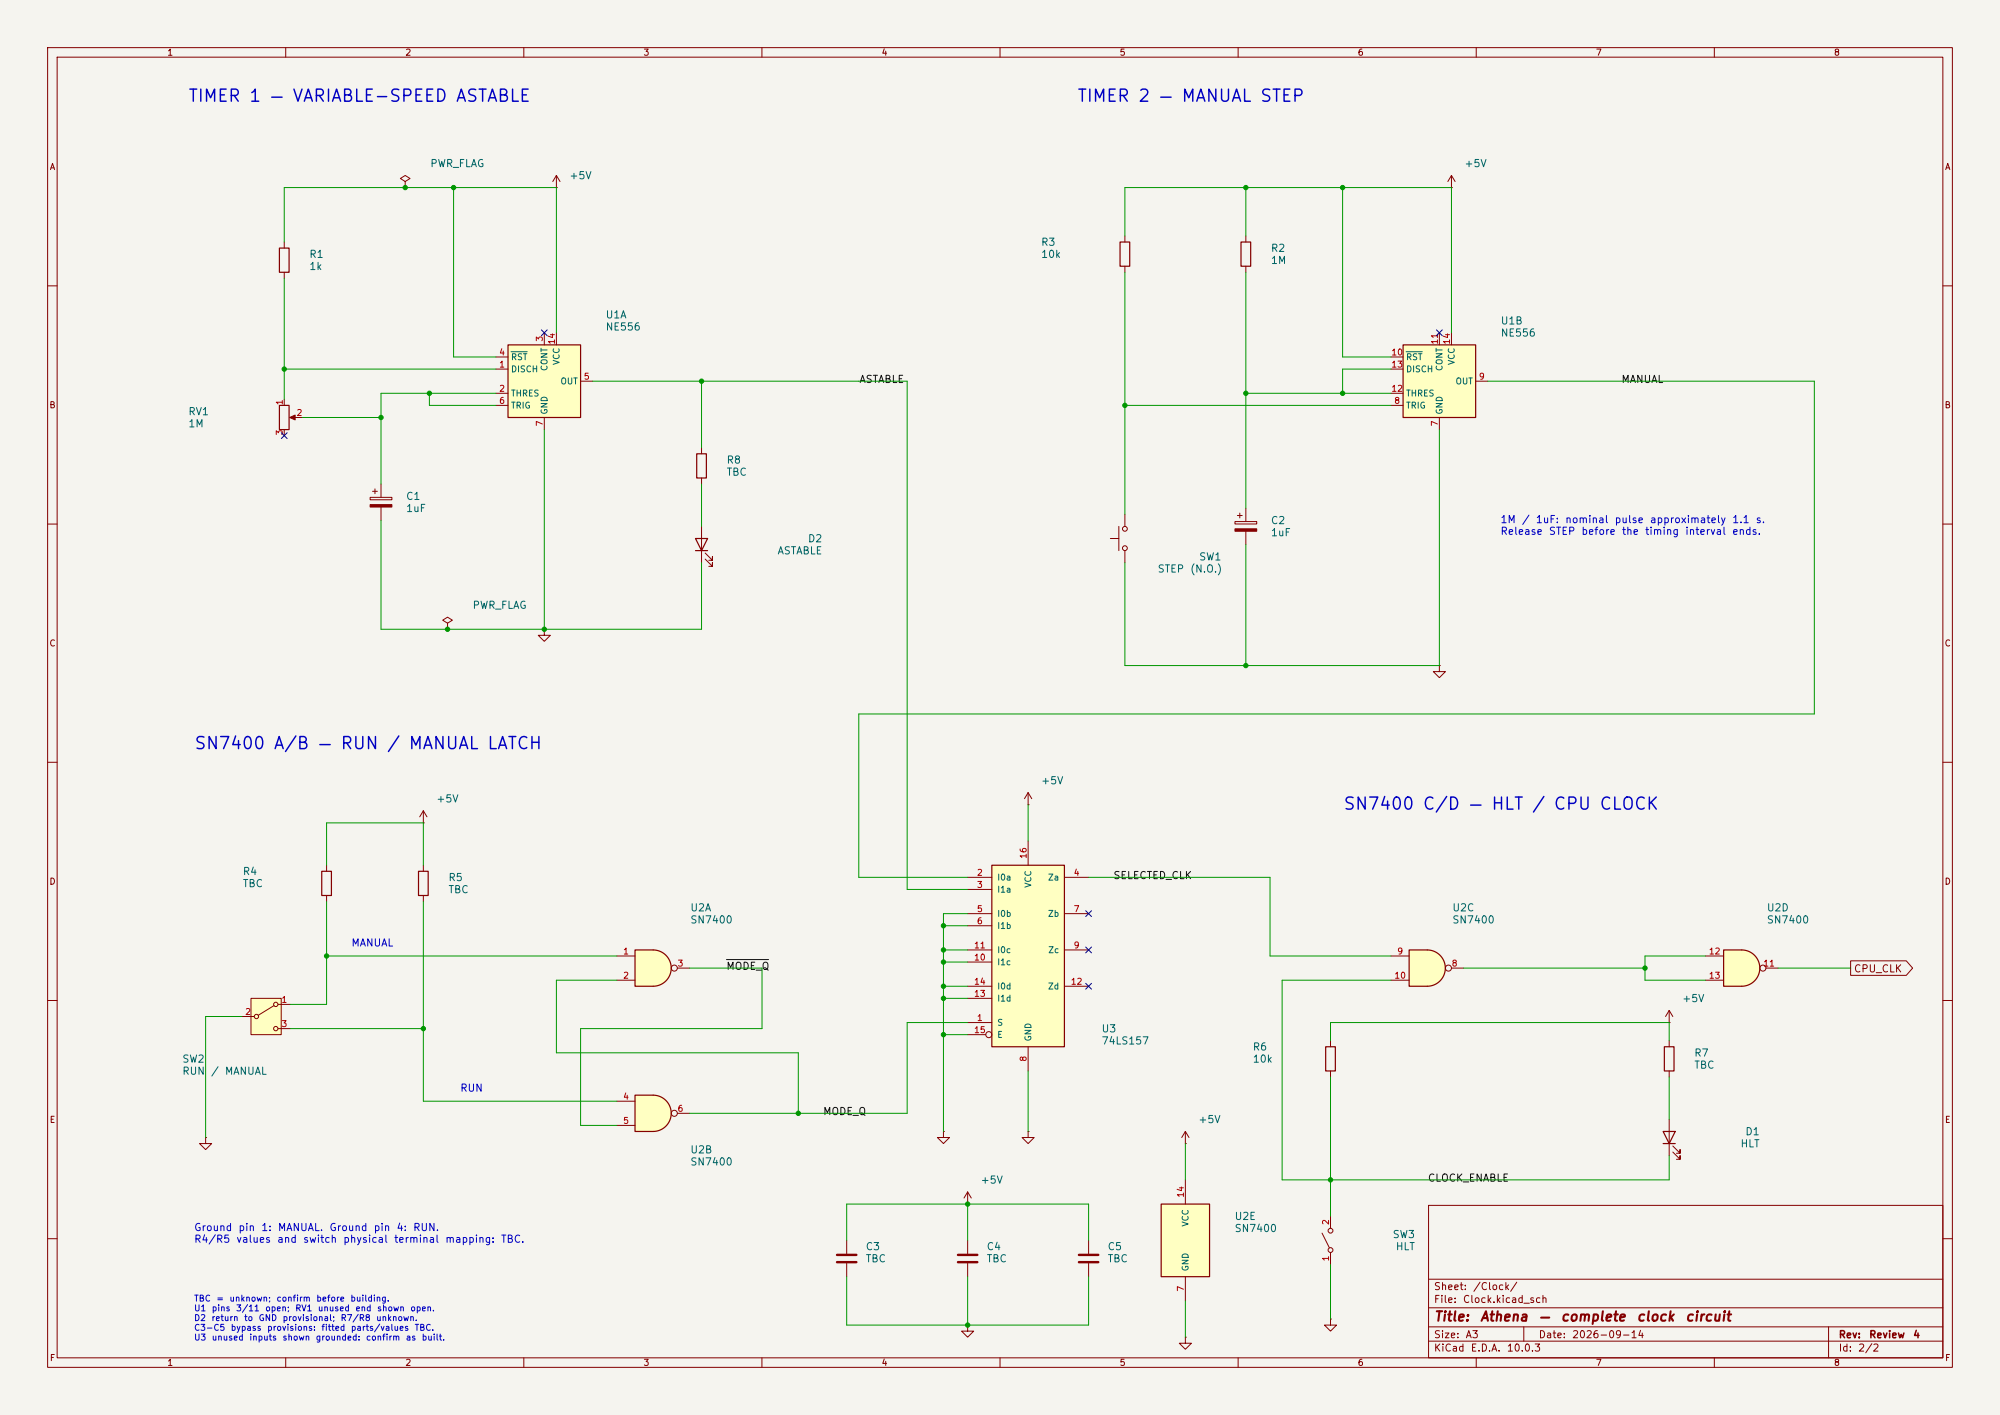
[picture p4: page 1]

1M / 1uF: nominal pulse approximately 1.1 s. Release STEP before the timing interval ends.

R4/R5 values and switch physical terminal mapping: TBC. TBC = unknown; confirm before building. U1 pins 3/11 open; RV1 unused end shown open. D2 return to GND provisional; R7/R8 unknown. C3-C5 bypass provisions: fitted parts/values TBC. U3 unused inputs shown grounded: confirm as built. MANUAL

Ground pin 1: MANUAL. Ground pin 4: RUN.

Sheet: /Clock/
File: Clock.kicad_sch
Title: Athena — complete clock circuit

Size: A3 | Rev: Review 4 | F Date: 2026-09-14
KiCad E.D.A. 10.0.3 | Id: 2/2

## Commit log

2026-09-13 Document current Athena clock architecture
2026-09-13 Add clock module wiring record
2026-09-13 Add 556 pin verification journal
2026-09-13 Record Timer 2 timing resistor fault
2026-09-13 Extend 556 verification through pin 12
2026-09-13 Align clock status summaries with pin 12 verification
2026-09-13 Add replacement datasheets, learning journal and KiCad project
    [Athena.kicad_pcb, Athena.kicad_sch, Clock.kicad_sch]
2026-09-14 Update Athena clock schematic and verification journal
    [Clock.kicad_sch]
2026-09-14 Update handover text and Kicad BoM and Schema
    [Athena.csv, Clock.kicad_sch]
2026-09-18 Document clock verification and initial Z80 bring-up
    [Athena.kicad_sch, Clock-logic.kicad_sch, DSLogic PLus-la-260918-221424.csv]
2026-09-18 Updated README to reflect pull requests and issues not currently accepted, but discussions welcome
2026-09-19 Document CD40106B STEP debounce wiring
2026-09-19 Correct clock device count after CD40106B addition
2026-09-19 Record CD40106B divergence in KiCad clock documentation
2026-09-19 Add CD40106BE STEP debounce to clock schematic
    [Clock.kicad_sch]
2026-09-19 Update clock logic diagram for STEP debounce
    [Clock-logic.kicad_sch]
2026-09-19 Update clock BOM for CD40106B debounce
    [Athena.csv]
2026-09-19 Synchronise KiCad clock documentation with debounce schematic
2026-09-19 Update clock and Z80 journals with 19 September bench evidence
    Preserve historical measurements and images; record debounce, RUN regression, selector checks and NMOS low-frequency findings. Qualify manual-step assumptions and document outstanding schematic discr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
